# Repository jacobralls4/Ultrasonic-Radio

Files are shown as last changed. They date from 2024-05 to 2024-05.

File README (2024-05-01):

This repo contains many files related to Team 84s Ultrasonic Radio Project. Here you can find key design files shown through Spice, Altium, and ss from multisim.
Along with this there are report files as well as a few of our presentation slides.
Additionally you can find screenshots showcasing key oscilloscope waveforms demonstrating successful validations of our project.

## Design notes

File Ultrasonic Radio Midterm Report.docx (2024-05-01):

Ultrasonic Radio

Nathan Cinocca

Concept of Operations

REVISION – Draft

25 January 2018

Concept of Operations

for

Ultrasonic Radio

Team 84

Approved by:

_____________________________

Project Leader Date

_____________________________

Prof. Kalafatis Date

_____________________________

T/A Date

Change Record

Rev. | Date | Originator | Approvals | Description
- | 9/14/2023 | Nathan Cinocca | | Draft Release

4.2. Submarine Communications………………………………………………………………4

# No table of figures entries found.

# 1. Executive Summary

Communicating information is an important aspect of almost any military operation. However, depending on the situation, it can be difficult to transmit information safely. For example, in planes and submarines it is difficult to communicate with regular equipment as the electromagnetic waves will interfere with the vehicles navigating equipment. To solve this issue, an ultrasonic radio will be developed that will operate at a low frequency using acoustic waves outside of the range of human hearing. The radio will also have multiple channels that will allow for two-way communications between correspondents. Ultimately, this radio will allow for better communication between military operators even around areas that are sensitive to electromagnetic waves.

# 2. Introduction

This report is an introduction to the development of an ultrasonic radio. This ultrasonic radio will be designed to operate using low frequency acoustic waves outside of the range of human hearing to transmit data without affecting other electromagnetic waves at higher frequencies. This ultrasonic radio will primarily be used for military operations that involve planes, submarines, and other forms of transportation with sensitive equipment. However, this radio could also be used by civilians in similar situations.

## 1.1. Background

Radios have been around for a very long time and operate at a large range of frequencies from 3 Hz to 300 GHz. However, most of these radios use electromagnetic waves to transmit information. Radios that use electromagnetic waves are effective methods of communication as they can send and receive information very quickly. Despite this electromagnetic wave-based communication can have problems where multiple devices create wave interference. This can be a very dangerous issue when sensitive, vital equipment such as airplane equipment is interfered with. The danger of electromagnetic wave interference is multiplied in dangerous military situations.

A way to get around the limitations posed by electromagnetic waves and their applications is to create an ultrasonic radio that uses acoustic waves. Using acoustic waves at lower frequencies will allow for minimal electromagnetic interference but will limit range of transmission. This trade off is acceptable as it will allow for safe communication during military operations in both planes and submarines.

In my research I have only found one ultrasonic acoustic radio that has been developed. This radio was developed by Qin Zhou, Jinglin Zhenga, Seita Onishia, M. F. Crommie, and Alex K. Zettl. Their ultrasonic radio is designed to operate at a band centered around 300 kHz with only a single channel. Their design is effective, but I plan to improve upon it by lowering the operational frequency to have less interference. I also plan to add multiple channels to allow for two-way communication.

## 1.2. Overview

There are many different parts involved in creating this ultrasonic radio and a large focus for this project will be designing individual parts. An overview of the components involved in this radio is as follows. Firstly, the incoming signal will be amplified using a transistor-based amplifier. Then the signal will be filtered using a bandpass circuit and moved to a higher frequency, if necessary, with a mixer. Next, the signal will be modulated using frequency modulation. Then the signal will be filtered once more for noise and amplified with a power amplifier of very large gain (~100 dB). After this the signal will pass through the input transducer and the output transducer. After the signal passes through the output transducer the signal will be amplified again using a transistor-based amplifier, and then filtered. Finally, the signal may be filtered again to reduce noise before the final signal is output.

## 1.3. Referenced Documents and Standards

- Graphene electrostatic microphone and ultrasonic radio (pnas.org) (https://www.pnas.org/doi/pdf/10.1073/pnas.1505800112)
- C95.1, Standard for Safety Levels with Respect to Human Exposure to Radio-Frequency Electromagnetic Fields, 3 kHz to 300 GHz

# 3. Operating Concept

## 1.4. Scope

The ultrasonic radio is primarily intended to be used for military operations in areas where electromagnetic communications are difficult. This primarily includes during plane and submarine transportation. The ultrasonic radio could also be used at a lower capacity by regular consumers during flights.

## 1.5. Operational Description and Constraints

The ultrasonic radio should be simple to operate and will be operable without any in-depth knowledge or training. Essentially you should be able to speak on one side of the radio and hear the output of your voice on the other side in relative clarity. The radio will also allow you to both speak and listen to noise at the same time. This will be accomplished through two frequency channels.

There are several constraints that come with this project. One of them is the cost constraint. As a capstone student, I am afforded $100 to spend on our project. Since I will need to purchase transducers at an absolute minimum which can be relatively expensive. Because of this I will most likely be using discrete components to design the amplifiers and filters. This will lead to more noise and less precision in the designs. Another constraint on this ultrasonic radio is that since the system will be using acoustic waves, the transmission of information will be slower than most electromagnetic wave transmissions.

## 1.6. System Description

The ultrasonic radio can be divided into roughly five different parts. These include signal amplifiers, filters, signal modulator/demodulator, power amplifier, and the input/output transducers.

The signal amplifier will be used to amplify the noise input and output from the radio. The signal amplifier will be designed from discrete transistors. I will attempt to keep the power consumption relatively low by limiting the voltage <10 V and current to <15mA.

The filters will primarily be used to get rid of noise. I will use an IC operational amplifier for this application instead of designing the amplifier from scratch. For the filters used for both the input and output signal I will need them to operate at two different frequencies to accommodate the different channel frequencies. These frequencies will be in the 50k Hz to 100k Hz range.

Next, I will need to design a frequency modulator and demodulator. To do this I will need an oscillator and some IC op amps. This will also include many resistors and capacitors to operate properly.

I will also design a power amplifier with transistors. This amplifier will need to have a very large gain of around 100 dBs. This will be important to allow the signal to be transmitted a large distance.

Finally, I will need to purchase transducers that will function with the rest of the circuit. They will also need to function within the channel frequencies of 50k Hz – 100kHz.

## 1.7. Modes of Operations

Many radios are only half-duplex and only allow for one party to speak at a time. With this set up, a button is typically needed to activate the transmission from one radio to the other. However, since this ultrasonic radio will be full-duplex and allow for both parties to speak at the same time, there will be no need for this mode.

Instead, ultrasonic will simply have two modes. The first being the on mode, or the mode that will allow signal transmission. The other mode will be the off mode where no power will be consumed, and no signal will transmit.

## 1.8. Users

The ultrasonic radio is primarily intended to be used by military personnel usually during plane and submarine transportation. The ultrasonic radio could also be used at a lower capacity by regular consumers during flights. The radio should be able to be used with very little experience and a short manual. Overall, the radio should be usable by both the military and civilians with relative ease.

## 1.9. Support

The ultrasonic radio will be intuitive to use and as such should be usable without many instructions. However, a short manual would be provided with some instructions should it be needed.

# 4. Scenario(s)

## 1.10. Plane Communications

The first scenario in which the ultrasonic radio could be used is in the case of plane transportations. To avoid the impact of electromagnetic waves the ultrasonic radio could be used by both military personnel and civilians traveling in planes. This would allow communication between individuals on and off the plane.

## 1.11. Submarine Communications

Similar to the first scenario the ultrasonic radio could be used to avoid electromagnetic wave interference with submarine instruments. This scenario is less applicable to the public as few civilians use submarines for transportation. The radio would allow contact between submarines or contact between submarines and individuals on land depending on the distance.

# 5. Analysis

## 1.12. Summary of Proposed Improvements

- Allows for safer communication around equipment sensitive to electromagnetic waves
- Improves upon old design to allow both parties to speak and listen simultaneously
- Communication system is easy to use

## 1.13. Disadvantages and Limitations

- The ultrasonic radio with acoustic waves will have less range than an electromagnetic radio
- Increased noise due to cheaper components from budget limitations
- Slower transfer of information due the low operational frequency

## 1.14. Alternatives

- Improved electromagnetic shielding
  - Shield sensitive plane/submarine components from all other EM waves so that regular electromagnetic communications can be used
  - Could be more effective but would be much more expensive and technically difficult

## 1.15. Impact

- The ultrasonic radio must abide by radio frequency standards
- The radio may be used to gain a tactical advantage in military operations

Ultrasonic Radio

Nathan Cinocca

Functional System Requirements

REVISION – Draft

28 September 2023

Functional System Requirements

for

Ultrasonic Radio

Prepared by:

Team 84

Approved by:

_____________________________

Nathan Cinocca Date

_____________________________

John Lusher, P.E. Date

_____________________________

T/A Date

Change Record

Rev. | Date | Originator | Approvals | Description
- | 9/28/2023 | Nathan Cinocca | | Draft Release

Table 2. Reference Documents……………………………………………….3

# 6. Introduction

## 1.16. Purpose and Scope

This document covers the functional system requirements for the project. The purpose of the project is to provide an alternative way to send communications that does not use electromagnetic waves. By limiting the creation of electromagnetic radiation, this ultrasonic radio will allow for communications in locations that are susceptible to electromagnetic interference. To do this, the radio will operate at lower ultrasonic frequencies as opposed to higher electromagnetic wave frequencies. Additionally, acoustic waves will be used instead of electromagnetic waves.

This specification defines the technical requirements for the development items and support subsystems delivered to the client for the project. Figure 1 shows a representative integration of the project in the proposed CONOPS. The verification requirements for the project are contained in a separate Verification and Validation Plan.

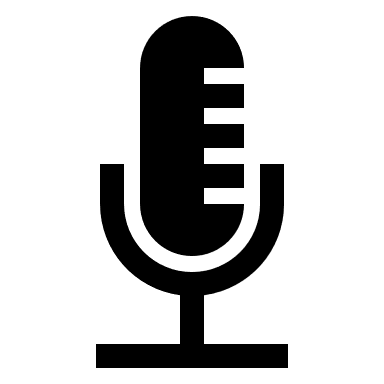
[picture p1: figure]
Radio microphone with solid fill
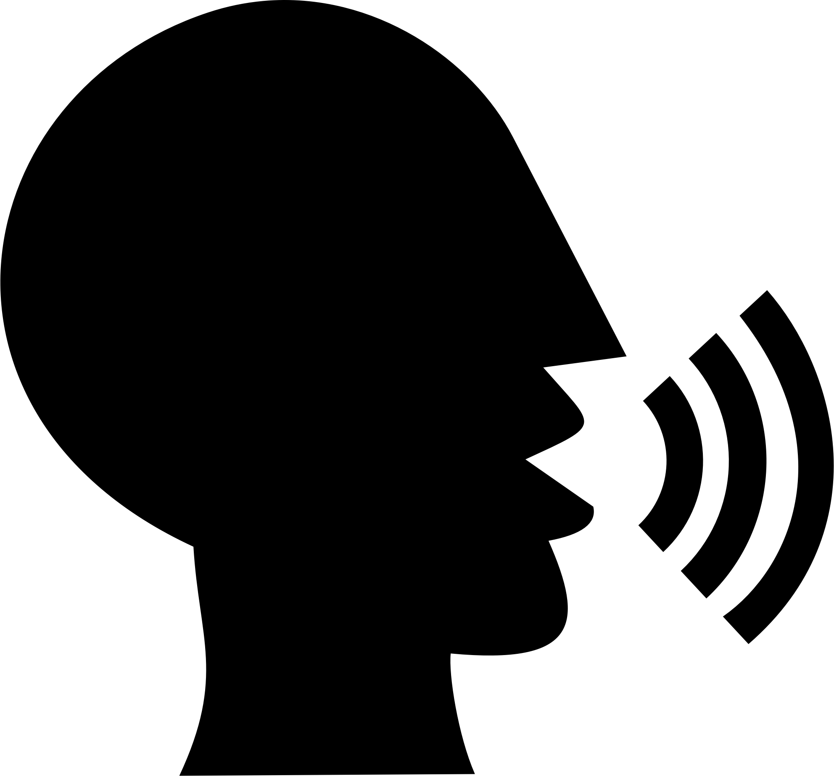
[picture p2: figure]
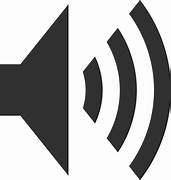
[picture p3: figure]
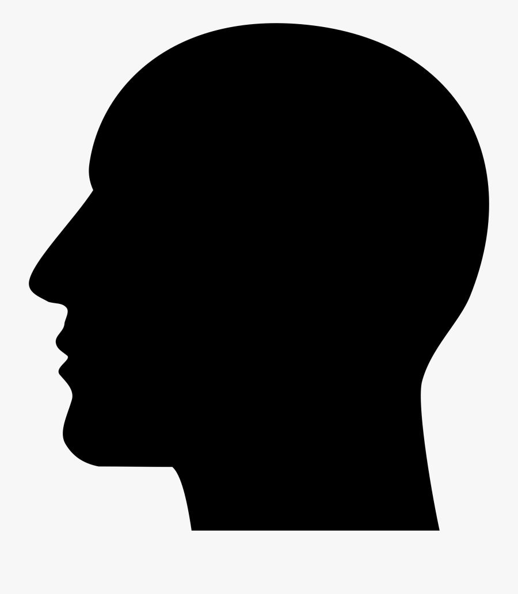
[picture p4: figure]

Microphone

Microphone

Speaker

Speaker

Ultrasonic Waves

Figure 1. Ultrasonic Radio Conceptual Image

The following definitions differentiate between requirements and other statements.

Shall: This is the only verb used for the binding requirements.

Should/May: These verbs are used for stating non-mandatory goals.

Will: This verb is used for stating facts or declaration of purpose.

## 1.17. Responsibility and Change Authority

The sole team member, Nathan Cinocca, will be responsible for verifying the requirements of the project are achieved. Any changes to the project may only be enacted through an agreement between Nathan Cinocca and the sponsor Dr. Oscar Moreira. Subsystem ownership for this project is listed below.

- Nathan Cinocca: Signal Amplifier, Filters, Modulator/Demodulator, and Power Amplifier

# 7. Applicable and Reference Documents

## 1.18. Applicable Documents

The following documents, of the exact issue and revision shown, form a part of this specification to the extent specified herein:

Document Number | Revision/Release Date | Document Title
IPC A-610E | Revision E – 4/1/2010 | Acceptability of Electronic Assemblies
MIL-STD-461 | Revision E – 8/20/1999 | Requirements for the Control of Electromagnetic Interface Characteristics of Subsystems and Equipment
ΙΕΕΕ Standard C95.1 | 4/16/1999 | Safety Levels with Respect to Human Exposure to Radio Frequency Electromagnetic Fields, 3 kHz to 300 GHz

Table 1. Applicable Documents

## 1.19. Reference Documents

The following documents are reference documents utilized in the development of this specification. These documents do not form a part of this specification and are not controlled by their reference herein.

Document Number | Revision/Release Date | Document Title
1 | 2015 | Graphene electrostatic microphone and ultrasonic radio
2 | 2010 | Analog and Digital Communications
3 | 2011 | RF and Microwave Transmitter design
4 | 2014 | FM Modulation/de-modulation circuit
5 | 2009 | Engineering Acoustics: An Introduction to Noise Control
5 | 2020 | Thermal Stress Inside a Disabled Submarine

Table 2. Reference Documents

## 1.20. Order of Precedence

In the event of a conflict between the text of this specification and an applicable document cited herein, the text of this specification takes precedence without any exceptions.

All specifications, standards, exhibits, drawings or other documents that are invoked as “applicable” in this specification are incorporated as cited. All documents that are referred to within an applicable report are considered to be for guidance and information only, except ICDs that have their relevant documents considered to be incorporated as cited.

# 8. Requirements

This section defines the minimum requirements that the development item(s) must meet. The requirements and constraints that apply to performance, design, interoperability, reliability, etc., of the system, are covered.

## 1.21. System Definition

Provide a brief overview of the project, and then describe some of the main sub-systems of your proposed solution.

The ultrasonic radio is a method of communication that limits the creation of electromagnetic waves so electromagnetic interference is minimized. By minimizing the emission of electromagnetic waves, this communication device will allow for information transfer around devices sensitive to other electromagnetic waves. This ultrasonic radio will limit electromagnetic wave emission by using acoustic waves and low ultrasonic frequencies to transmit information. The ultrasonic radio is largely made up of five different subsystems. These subsystems include: the signal amplifier, filters, power amplifier, modulator/ demodulator, and the speakers/microphones.

Voice Input

Demodulator

Amplifier and Filter

Transmitter/ Receiver

Filter and Power Amplifier

Modulator

Amplifier and Filter

Filter and Output Voice

Figure 2. Block Diagram of System

The first part of the ultrasonic radio is the input microphone which will operate to encompass human voice frequencies. This range of operational frequencies will be around 100 Hz to 3 kHz. This microphone will translate the voice into an electrical signal that will then be amplified and filtered through the signal amplifier and low frequency filter. This will make the signal stronger and filter out unneeded noise being picked up by the microphone. Following this, the signal will go through a modulating circuit which moves the input signal to ultrasonic frequencies to prepare for transmission. After modulation, the signal may be filtered if additional noise is picked up at the higher ultrasonic frequency. Then the modulated signal will go through the power amplifier which will give the signal the desired gain to transmit through the ultrasonic speaker to the ultrasonic microphone some distance away. Once the signal is picked up by the microphone it will be filtered and amplified again to prepare for demodulation. Then the signal will be demodulated down to frequencies within the range of human hearing. Finally, the signal may be filtered again if necessary and then it will be output through a speaker operating within the range of human hearing.

## 1.22. Characteristics

### 8.1.1. Functional / Performance Requirements

#### 8.1.1.1. Signal to Noise Ratio

The transferred signal from the ultrasonic radio shall have at least a 60 dB signal to noise ratio.

Rationale: Typical audio equipment that functions well has a signal to noise ratio of at least 60 dB. Very good audio equipment has even higher decibels. Since the ultrasonic radio should have a clear signal so communications can happen cleanly 60 dB is required.

#### 8.1.1.2. Transmission Distance

The ultrasonic radio shall meet a communication distance of 15 meters or more.

Rationale: Although a long transmission distance for the ultrasonic radio is better, there are limitations from testing and the ultrasonic nature of the waves. Knowing this, a transmission distance of 15 meters or more will allow for a usable and testable ultrasonic radio.

#### 8.1.1.3. Total Harmonic Distortion

The ultrasonic radio shall have a total harmonic distortion of less than or equal to 5%.

Rationale: It is important to keep total harmonic distortion low to keep good audio quality. Typically, a total harmonic distortion level less than or equal to 5% is acceptable and is the goal for this ultrasonic radio.

### 8.1.2. Physical Characteristics

#### 8.1.2.1. Mass

The mass of the ultrasonic radio shall be less than or equal to 10 kilograms.

Rationale: While there isn’t a specific weight requirement for the ultrasonic radio, it should be relatively easy to move around for maximum use. A weight of up to 10 kilograms should be easy for any military man/woman to move.

### 8.1.3. Electrical Characteristics

#### 8.1.3.1. Inputs

The electrical inputs should not be changed by users of the ultrasonic radio. All tests will be performed under these conditions and system performance under separate conditions is not guaranteed.

##### 8.1.3.1.1 Power Consumption

The maximum peak power of the system shall not exceed 4.5 watts.

Rationale: This requirement is due to the power of the system being provided by a USB wall adapter. The maximum power provided by USB 3.0 is 4.5 watts, so that is the maximum power limit.

##### 8.1.3.1.2 Input Voltage Level

The input voltage level for the ultrasonic radio shall be +5 VDC.

Rationale: USB wall adapter has a voltage level of 5 VDC which will be used to power the ultrasonic radio.

##### 8.1.3.1.3 Input Current Level

The input current for the ultrasonic radio shall not exceed 900 mA.

Rationale: 900 mA is the maximum current that can be supplied by the USB 3.0 wall adapter and is thus the maximum current that can be supplied to the ultrasonic radio.

##### 8.1.3.1.4 Voice Input

The ultrasonic radio shall take user voice input that operates from 100 Hz to 3 kHz.

Rationale: The ultrasonic radio needs to be able to handle any range of human voice frequencies and transmit them.

#### 8.1.3.2. Outputs

##### 8.1.3.2.1 Voice Output

The ultrasonic radio shall output the voice input up to 15 meters away at frequencies 100 Hz to 3 kHz.

Rationale: The ultrasonic radio will allow communications to pass into the microphone and out through the output speaker a distance up to 15 meters away to satisfy the conditions of a radio.

### 8.1.4. Environmental Requirements

The ultrasonic radio shall be designed to withstand and operate in the environments and laboratory tests specified in the following section.

Rationale: This is a requirement specified by the intended usage of the ultrasonic radio

#### 8.1.4.1. Pressure (Altitude)

The ultrasonic radio may be able to operate up to 2.5 atm of pressure.

Rationale: The internal pressure of a typical military submarine is roughly equivalent to 2.5 atm. Thus, to perform its function, the ultrasonic radio should be able to function up to this amount of pressure.

#### 8.1.4.2. Thermal

The ultrasonic radio may be able to operate at thermal temperatures ranging from 55 degrees Fahrenheit to 95 degrees Fahrenheit.

Rationale: The internal thermal temperatures of a military submarine without power can range from 55 degrees Fahrenheit to 95 degrees Fahrenheit in extreme scenarios. So, the ultrasonic radio should be able to function in these emergencies.

#### 8.1.4.3. Humidity

The ultrasonic radio should be able to function in 0-95% relative humidity.

Rationale: The internal relative humidity of a military submarine without power can range from 0-95% relative humidity in extreme scenarios. So, the ultrasonic radio should be able to function in these emergencies.

### 8.1.5. Failure Propagation

##### 3.2.5.1 Recovery

The Ultrasonic radio should provide a way to reset the entire system.

Rationale: This is a feature of the radio that should help fix errors that occur with the ultrasonic radio.

# 9. Support Requirements

4.1.1 Ultrasonic Radio Manual

To help users understand how to use the ultrasonic radio, a manual that details some of the parts of the radio and generally how to use it will be provided to customers.

Rationale: This feature will help users better understand the ultrasonic radio which will allow for improved usage of the device.

4.1.2 Power Adapter

Users of the ultrasonic radio will be provided with a USB power adapter to power the radio. However, clients must have access to a wall outlet to use the USB adapter and power the radio.

Rationale: Providing the power adapter will ensure that the correct power source is used for the ultrasonic radio. It will also allow the users to spend less time before the radio is operational.

# Appendix A: Acronyms and Abbreviations

ATM Atmosphere

CONOPS Concept of Operations Document

dB Decibels

Hz Hertz

ICD Interface Control Document

Kg kilograms

kHz Kilohertz (1,000 Hz)

mA Milliamp

MHz Megahertz (1,000,000 Hz)

SNR Signal to Noise Ratio

USB Universal Serial Bus

VDC Direct Current Voltage

# Appendix B: Definition of Terms

Electromagnetic waves Waves produced by the movement of electric charge and the propagation of electric and magnetic fields.

Electromagnetic radiation When electromagnetic waves interfere with each other when they should not

Receiver Equipment that accepts transmitted waves carrying signals from another location

Transmitter Equipment that generates and transmits waves carrying signals to another location

Ultrasonic A range of frequencies from 20 kHz to 20 MHz

Ultrasonic Radio

Nathan Cinocca

Interface Control Document

REVISION – Draft

28 September 2023

Interface Control Document

for

Ultrasonic Radio

Prepared by:

Team 84

Approved by:

_____________________________

Nathan Cinocca Date

_____________________________

John Lusher II, P.E. Date

_____________________________

T/A Date

Change Record

Rev. | Date | Originator | Approvals | Description
- | 9/28/2023 | Nathan Cinocca | | Draft Release

# No table of figures entries found.

# 10. Overview

This Interface Control Document (ICD) will provide detail on how the various subsystems of the ultrasonic radio will function together. This document will also detail physical descriptions of various subsystems of the ultrasonic radio. The Interface Control Document will also explain how the subsystems will interface together to meet the requirements explained in the Functional System Requirements document and ConOps document.

# 11. References and Definitions

## 1.23. References

Refer to section 2.2 in the Functional System Requirements document.

## 1.24. Definitions

ATM Atmosphere

CONOPS Concept of Operations Document

dB Decibels

Hz Hertz

ICD Interface Control Document

Kg kilograms

kHz Kilohertz (1,000 Hz)

mA Milliamp

MHz Megahertz (1,000,000 Hz)

Mm Millimeter

mW Milliwatt

SNR Signal to Noise Ratio

TBD To be determined

USB Universal Serial Bus

VDC Direct Current Voltage

W Watt

# 12. Physical Interface

## 1.25. Weight

The overall weight of the system is difficult to determine at the current time as many of the subsystems have not been designed yet. The design of the systems will determine how many transistors, resistors, capacitors, and operational amplifiers will be used. All these components are light and should not add excessive weight. The heaviest subsystem in the ultrasonic radio will be the speakers and microphones. Although the speakers and microphones will be heavier compared to the transistors and other circuit elements, they are still quite small and light. Thus, it should not be difficult to keep the entire radio under 10 kilograms.

## 1.26. Dimensions

The dimensions of the entire ultrasonic radio should be kept under 1 cubic foot in size.

Similar to the weight section, since many subsystems are still being designed it is difficult to give accurate dimensions for each of the subsystems. However, most of the components are quite small. For example, the 2N3904 transistor which will be used is 36 mm x 18 mm x 1.5 mm. So, even using 100 transistors will still allow lots of space for the microphones, operational amplifiers, and other circuit elements. Op amp 743, which will be used in filters, and modulation/demodulation circuits has dimensions of 356 mm x 356 mm x 35 mm, which again is small even if many are used. Currently, the microphones and speakers that are being considered are also small at about 10 mm x 10mm x 3.5 mm. Since all the parts are small the ultrasonic radio should be able to meet the dimension requirement of 1 cubic foot.

# 13. Thermal Interface

Since the ultrasonic radio will be functioning at relatively low power, it will not need any heat sink to maintain low heat and high efficiency.

# 14. Electrical Interface

## 1.27. Primary Input Power

The ultrasonic radio has a maximum power of 4.5 watts. More specifically this is 5 V and 900 mA of current supplied by a USB 3.0 adapter. Although the power supplied to each subsystem is TBD at this point, since most are being designed, some maximum power requirements can be determined. This will be discussed in section 5.2.

## 1.28. Voltage and Current levels

- Signal amplifiers shall have no more than 50 mA and 5 V for 250 mW of power
- Filters shall have no more than 15 mA and 5 V for 75 mW of power
- Modulator/demodulators shall have no more than 100 mA and 5 V for 500 mW of power
- Power amplifiers shall have no more than 300 mA and 5 V for 1.5 W of power
- Speaker and microphones shall have no more than 350 mA and 5 V for 1.75 W of power

# 15. Communications / Device Interface Protocols

## 1.29. Communications Safety

Although this radio operates at a frequency that can not be heard by the human ear. The ultrasonic radio can still cause hearing loss from excessive exposure to ultrasonic frequencies. Thus, clients that are using the ultrasonic radio for extended amounts of time should wear ear protection.

Ultrasonic Radio

Nathan Cinocca

Schedule and Validation

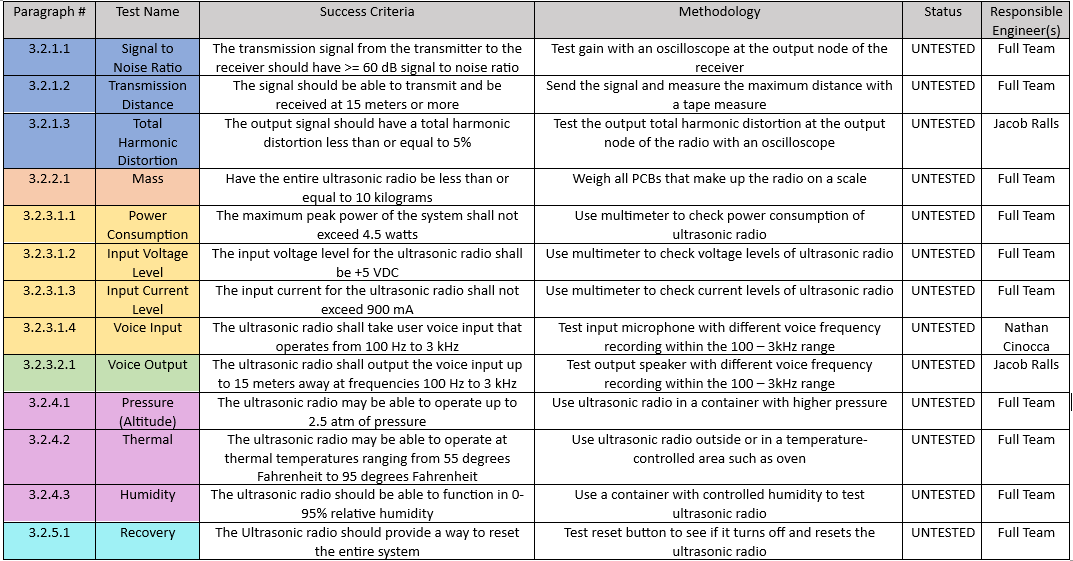
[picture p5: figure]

Calibrated LWIR Raw Video Data Collection - Gold Standard – Test 1 Revision -

Concept of Operations Revision – Draft Project Name

Functional System Requirements Revision - Draft Ultrasonic Radio

Schedule and Validation Revision - Ultrasonic Radio

Concept of Operations Revision - Project Name

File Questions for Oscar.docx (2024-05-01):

Questions for Oscar

- How high of a gain would be required to transmit the signal maybe 50 feet? Or how would I figure that out?
  - Want 60 dB signal to noise ratio
  - Some is lost in transmission
- How much gain for the signal amplifier?
- What 5V supply did you mention in our meeting before?
  - 5v usb adapter 1 W
- 3.2.4. Environmental Requirements The Search and Rescue System shall be designed to withstand and operate in the environments and laboratory tests specified in the following section. Rationale: This is a requirement specified by our customer due to constraints of their system in which the Search and Rescue System is integrating. 3.2.4.1. Pressure (Altitude) 3.2.4.2. Thermal 3.2.4.3. External Contamination 3.2.4.4. Rain 3.2.4.5. Humidity etc....you get the idea

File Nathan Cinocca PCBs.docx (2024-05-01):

Nathan Cinocca PCBs

Signal ampllifier

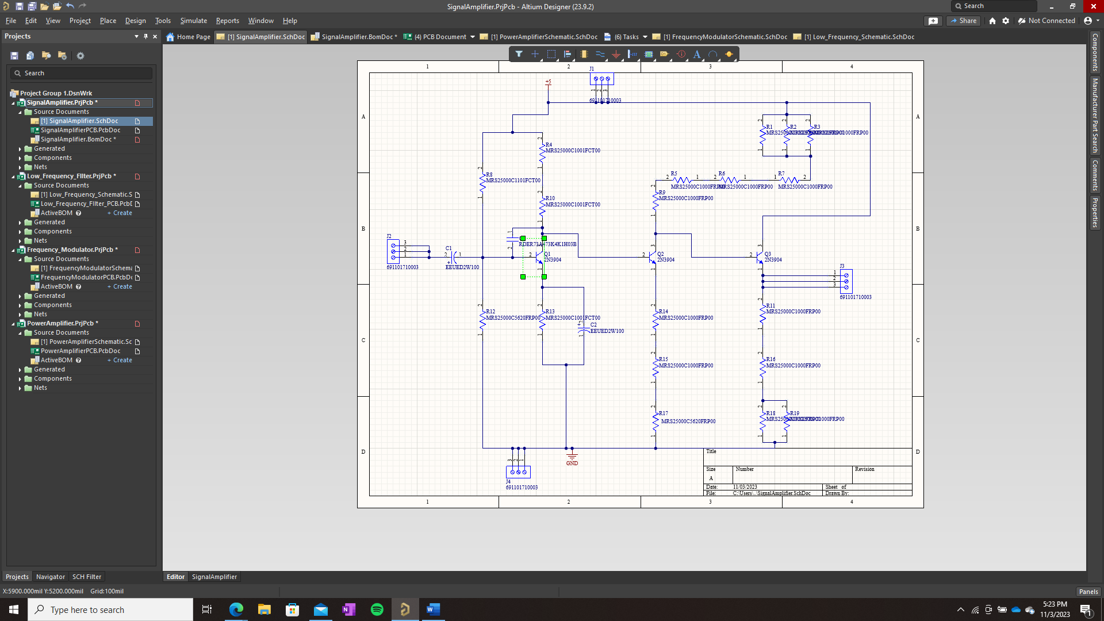
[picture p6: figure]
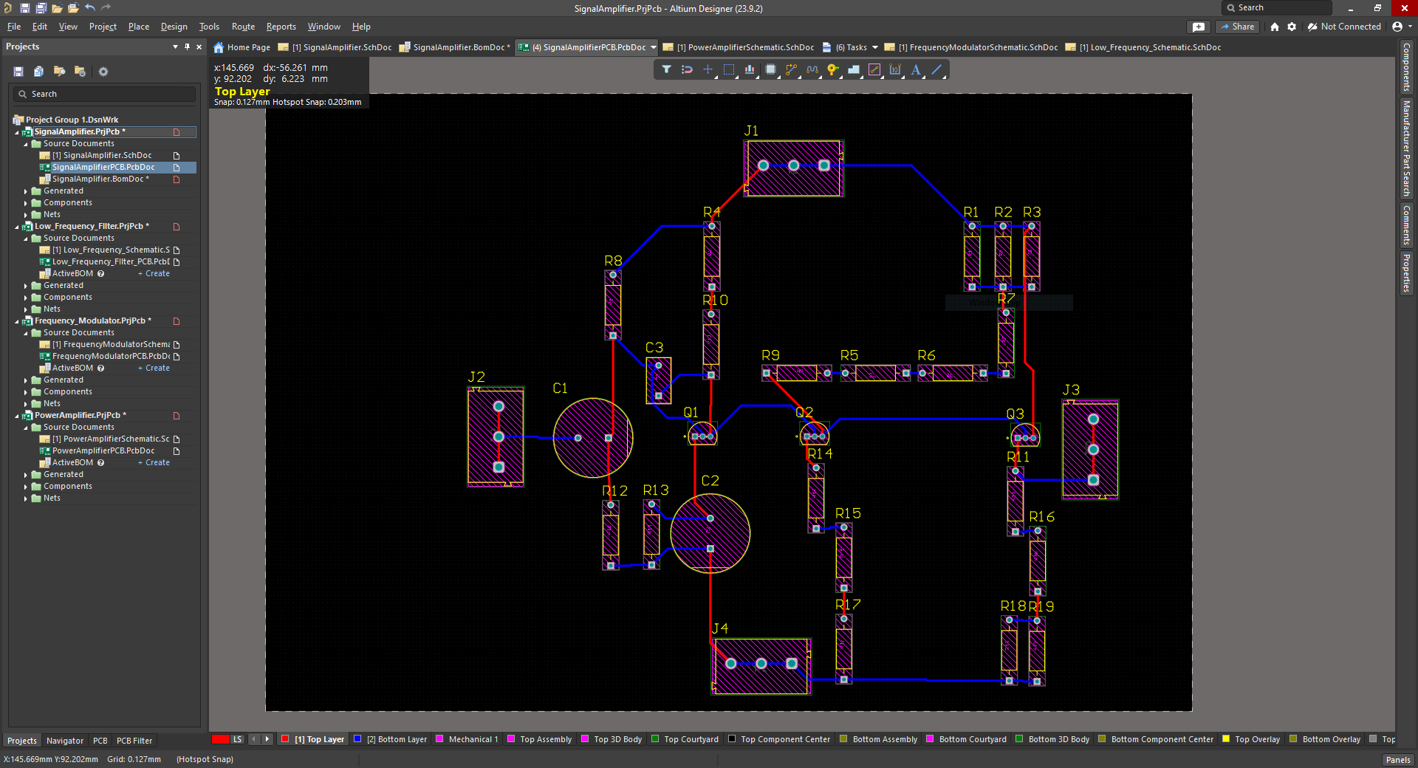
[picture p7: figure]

Filter

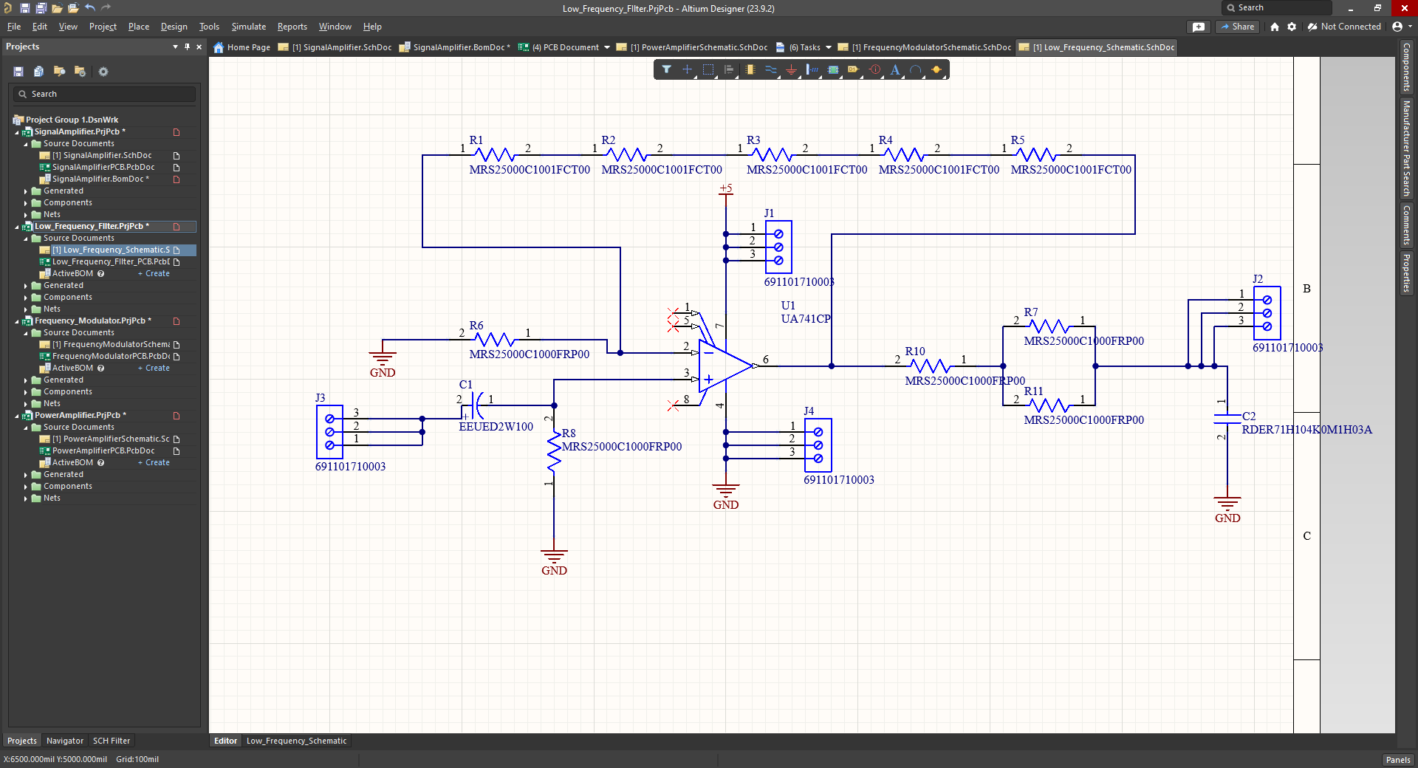
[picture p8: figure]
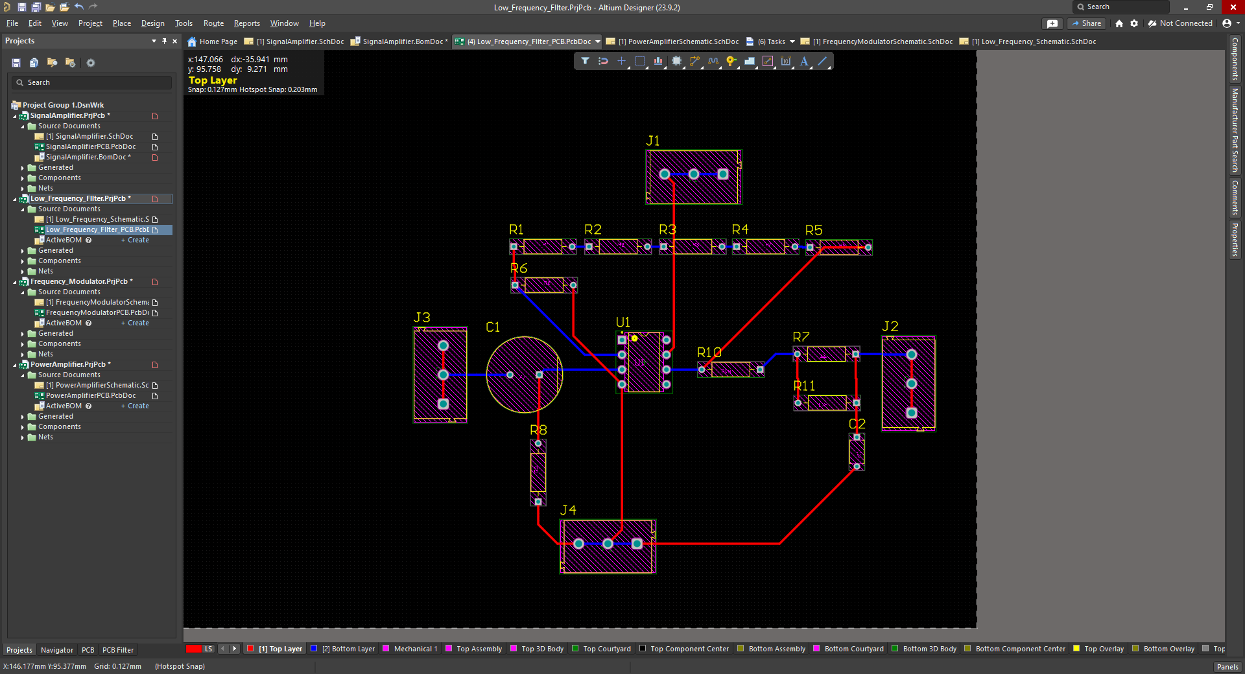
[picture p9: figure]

Frequency Modulator

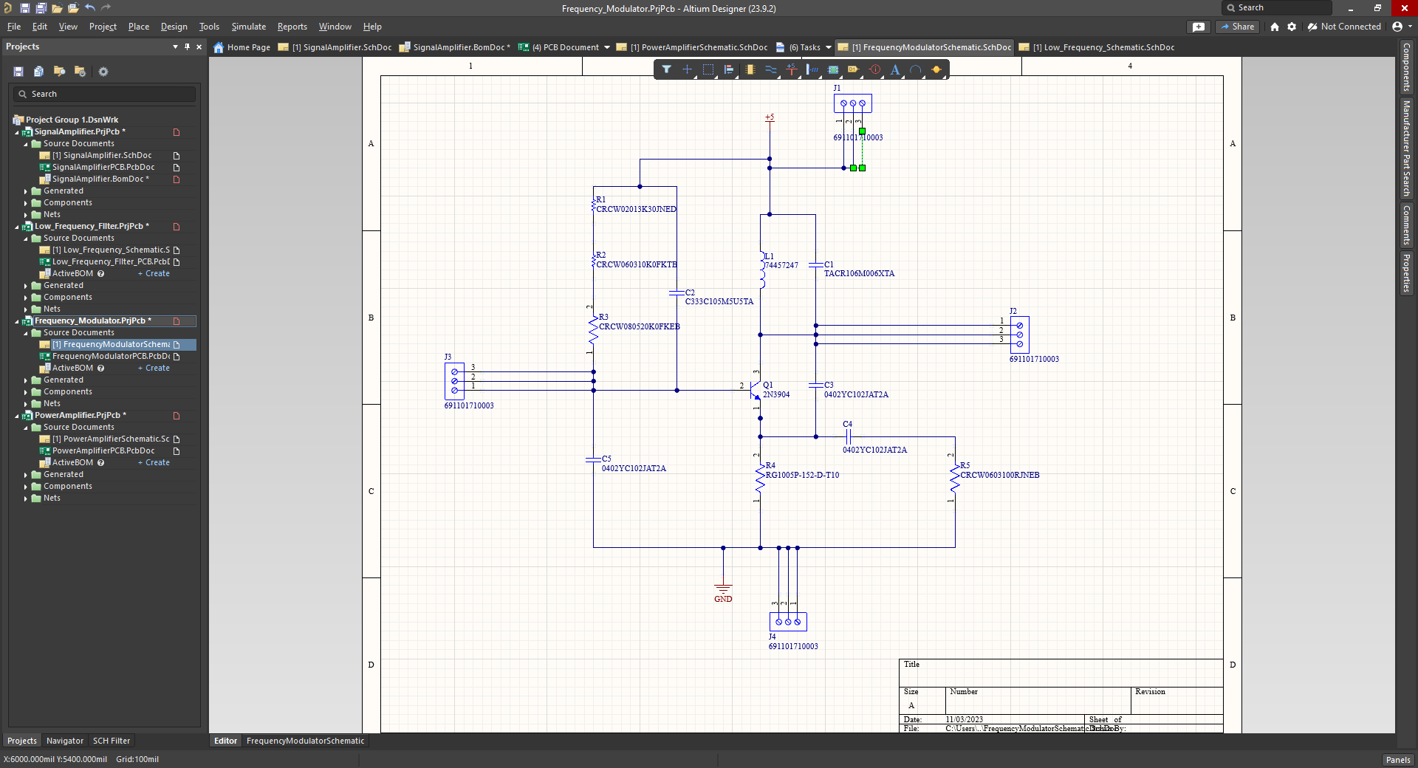
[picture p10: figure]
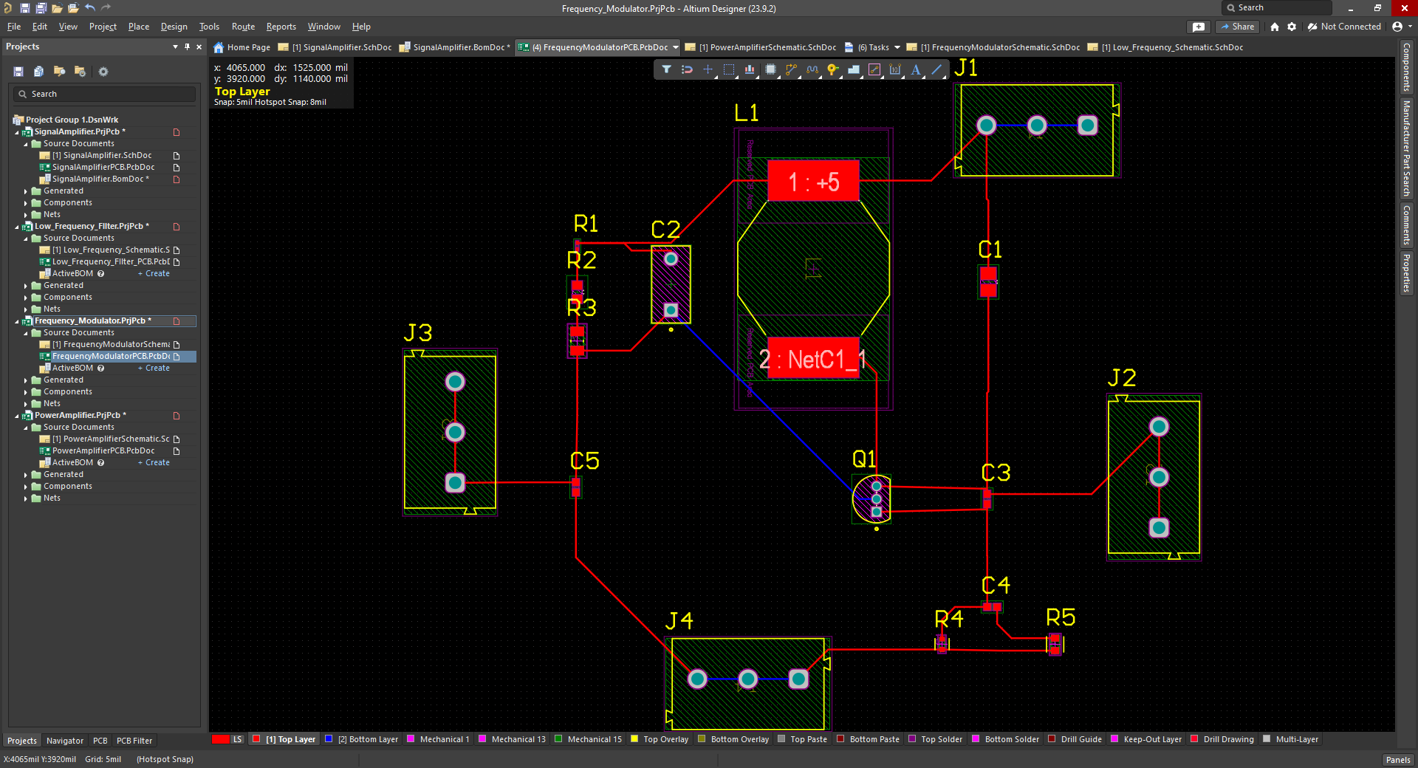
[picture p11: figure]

Power Amplifier

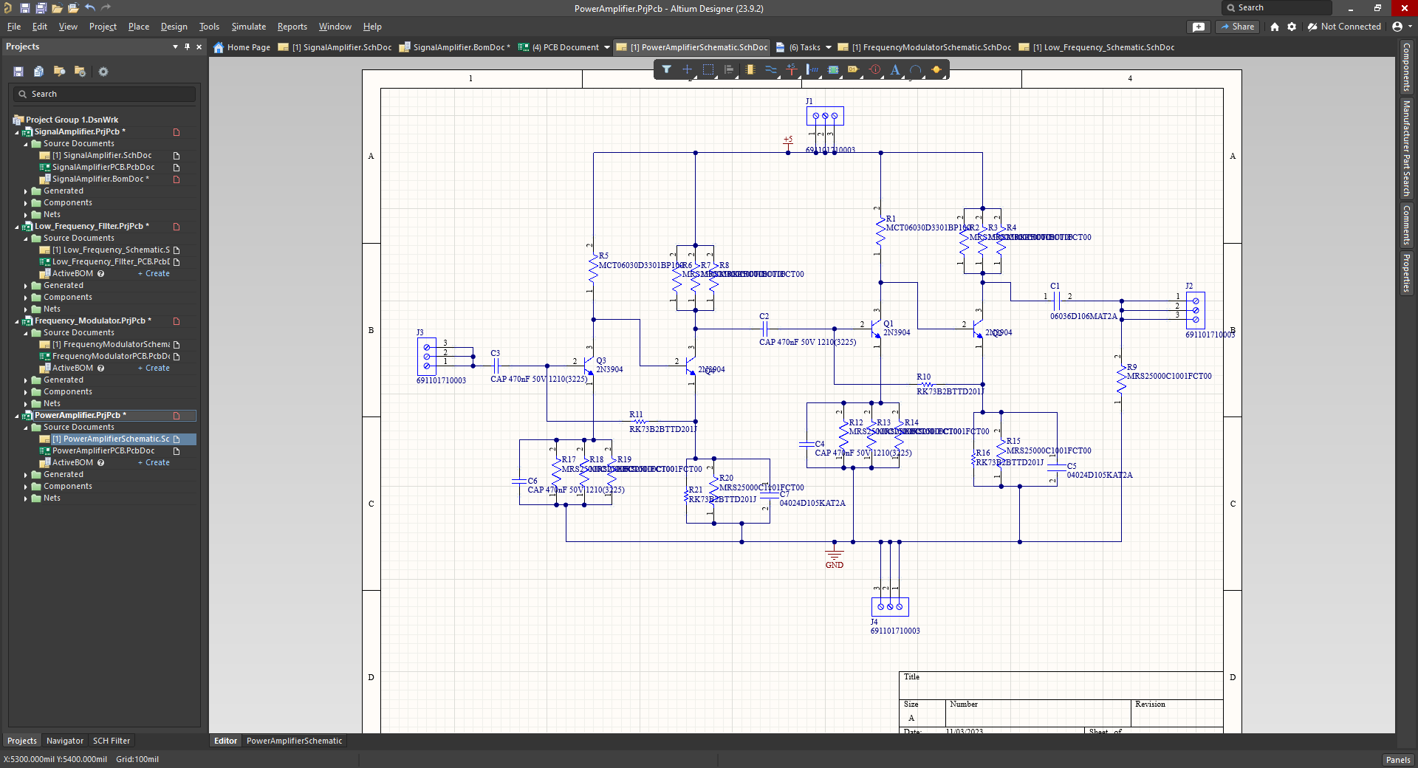
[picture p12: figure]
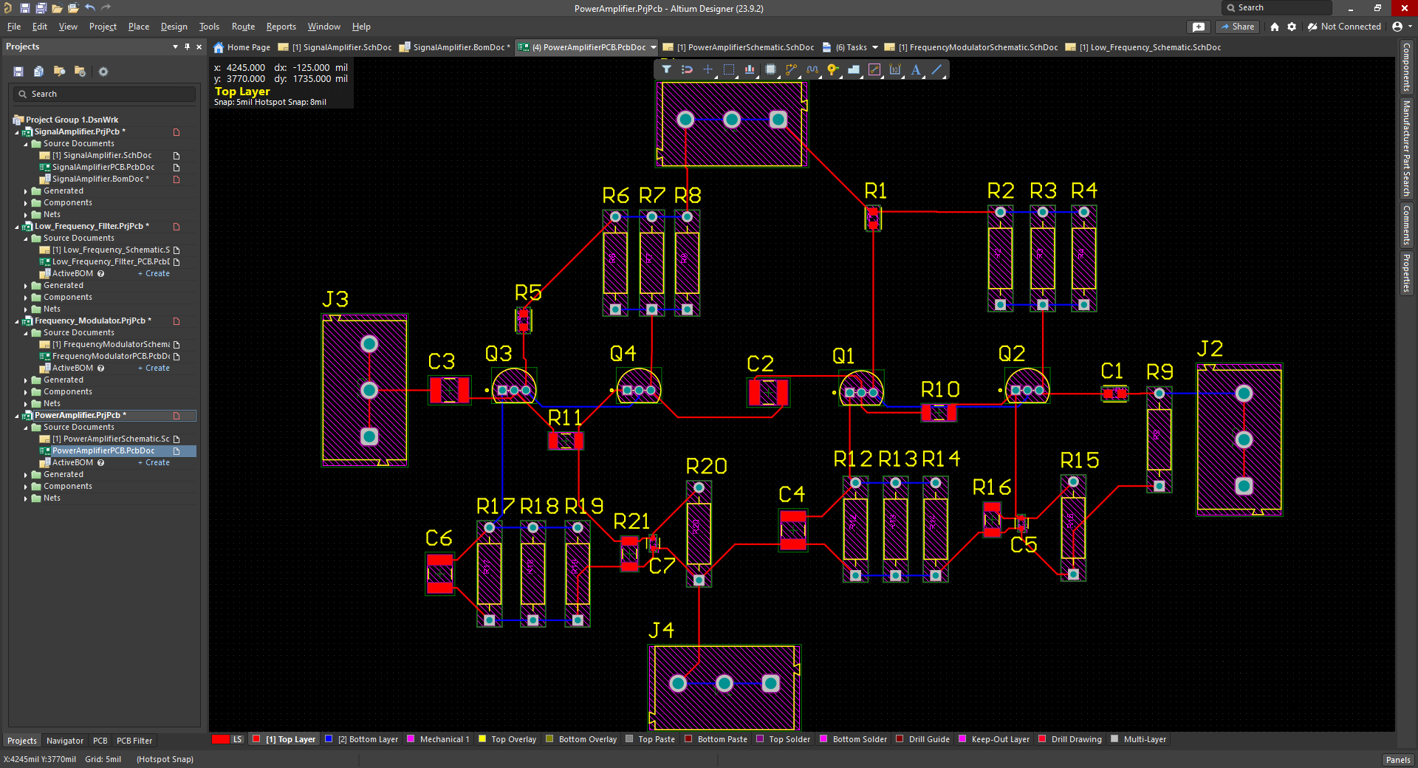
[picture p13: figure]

Paragraph # | Test Name | Success Criteria | Methodology | Status | Responsible Engineer(s)
13.2.1.1 | Total Harmonic Distortion | The output signal should have a total harmonic distortion less than or equal to 10% | Test the output total harmonic distortion at the output node of the radio with an oscilloscope | TESTED | Jacob Ralls
13.2.1.2 | Frequency Match | The transmitted signal frequency and tuned demodulator frequency should be matched within 3 kHz | Measure the modulator frequency and demodulator frequency with an oscilloscope | TESTED | Full Team
13.2.2.1 | Mass | Have the entire ultrasonic radio be less than or equal to 10 kilograms | Weigh all PCBs that make up the radio on a scale | TESTED | Full Team
13.2.3.1.1 | Power Consumption | The maximum peak power of the system shall not exceed 4.5 watts | Use multimeter to check power consumption of ultrasonic radio | TESTED | Full Team
13.2.3.1.2 | Input Voltage Level | The input voltage level for the ultrasonic radio shall be +5 VDC for the transmitter and +9 VDC for receiver | Use multimeter to check voltage levels of ultrasonic radio | TESTED | Full Team
13.2.3.1.3 | Input Current Level | The input current for the ultrasonic radio shall not exceed 900 mA | Use multimeter to check current levels of ultrasonic radio | TESTED | Full Team
13.2.3.1.4 | Voice Input | The ultrasonic radio shall take user voice input that operates from 100 Hz to 3 kHz | Test input microphone with different voice frequency recording within the 100 – 3kHz range | TESTED | Nathan Cinocca
13.2.3.2.1 | Voice Output Frequency | The ultrasonic radio shall output the voice input at frequencies 100 Hz to 3 kHz | Test output speaker with different voice frequency recording within the 100 – 3kHz range | TESTED | Jacob Ralls
13.2.3.2.2 | Voice Output Volume | The ultrasonic radio shall be heard from up to 15 meters away | Measure output volume in decibels to determine audible distance of output noise | TESTED | Jacob Ralls
13.2.4.1 | Pressure | The ultrasonic radio may be able to operate at 1 atm of pressure | Use ultrasonic radio in a standard room with 1 atm of pressure | TESTED | Full Team
13.2.4.2 | Thermal | The ultrasonic radio may be able to operate at thermal temperatures ranging from 55 degrees Fahrenheit to 95 degrees Fahrenheit | Use ultrasonic radio outside at different temperatures | TESTED | Full Team
13.2.5.1 | Recovery | The Ultrasonic radio should provide a way to reset the entire system | Reset the system by unplugging power supply from both transmitter and receiver for 10 seconds to reset system | TESTED | Full Team

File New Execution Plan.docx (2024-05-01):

| January 29th | February 5th | February 12th | February 19th | February 26th | March 4th | March 11th | March 18th | March 25th | April 1st | April 8th | April 15th
Finish Validating and Testing all Subsystems (ALL)
Order New PCB if Needed (ALL)
Order Ultrasonic Microphones and Speakers (ALL)
(Transmitter End) Connect/Validate Signal Amplifier and Filter (NC)
(Transmitter End) Connect/Validate Power Amplifier With Other Transmission Subsystems (NC)
(Transmitter End) Connect/Validate Frequency Modulator With Other Transmission Subsystems (NC)
(Receiver End) Connect/Validate Signal Amplifier and Filter (JR)
Connect/Validate Both Transmitter and Receiver Parts of Radio (ALL)
Final Validation and Testing of Radio (ALL)

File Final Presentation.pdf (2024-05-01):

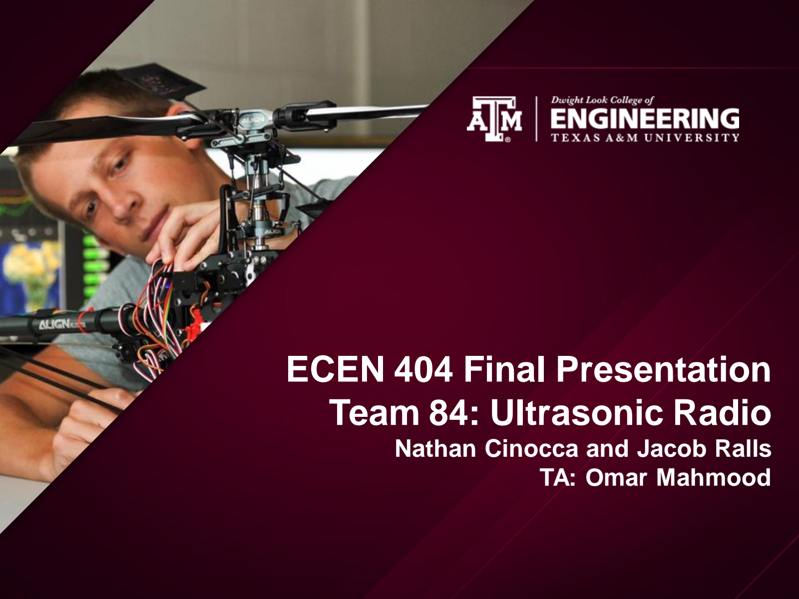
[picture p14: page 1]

# ECEN 404 Final Presentation Team 84: Ultrasonic Radio

### Nathan Cinocca and Jacob Ralls TA: Omar Mahmood

# Project Summary

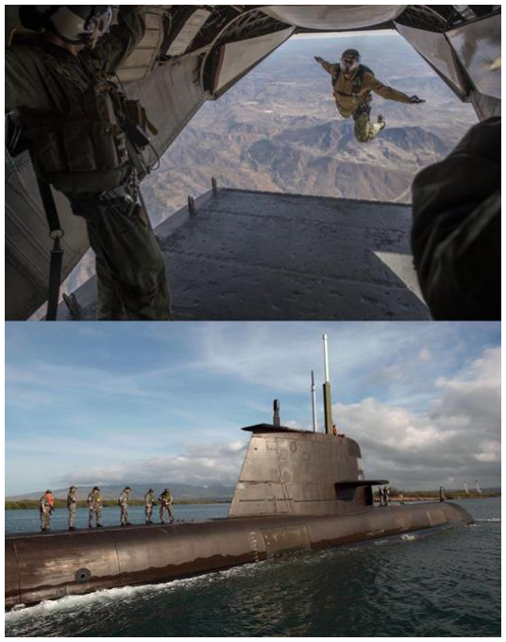
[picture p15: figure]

Problem statement:
- Communicating information is very important in almost every military operation. However, sometimes sending information through traditional methods is not feasible.
Solution proposal:
- A solution to this issue is to develop an acoustic ultrasonic radio.
– Acoustic waves and lower frequencies will limit
electromagnetic radiation
- This radio will allow for communications over relatively short distances.
- Communication will be slower than devices using electromagnetic waves

## Inegrated Project Diagram

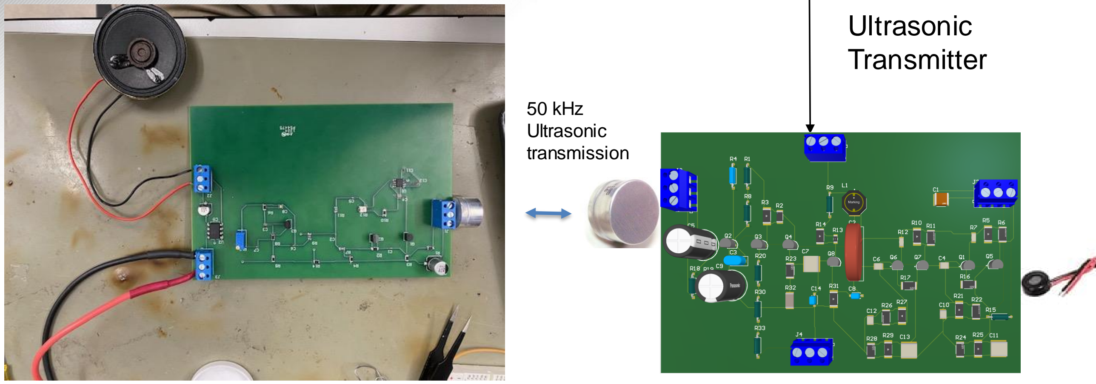
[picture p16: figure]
50 kHz Ultrasonic transmission; Ultrasonic Transmitter

- Input microphone covers human voice frequencies (100 Hz to 3 kHz)
- Voice is translated into an electrical signal
- Signal is amplified and filtered to enhance quality and eliminate unwanted noise
- Modulated to ultrasonic frequencies for transmission, with optional additional filtering
- Modulated signal goes through a power amplifier to achieve required gain
- Signal travels to receiving microphone for filtering and amplification for demodulation
- After demodulation, signal is filtered and output through a speaker within the human hearing range
- User uses R13 potentiometer as a volume adjuster of the output
- User uses R12 potentiometer as a means to filter input frequency ranges to be demodulated

Ultrasonic
Receiver

# Jacob Ralls

Designed, Tested, and Validated | Challenges Faced/Solutions Found
- Initially designed and tested individual working demodulator circuit • Designed and tested 4th Order Chebyshev Band Pass Filter • Designed and tested 2nd order Bessel filter design | • Prob: Band Pass Filter did not properly represent the gain shown in both LTSpice and Multisim simulations • Sol: Designed a simplified model with a focus on gain at a cost of bandwidth.

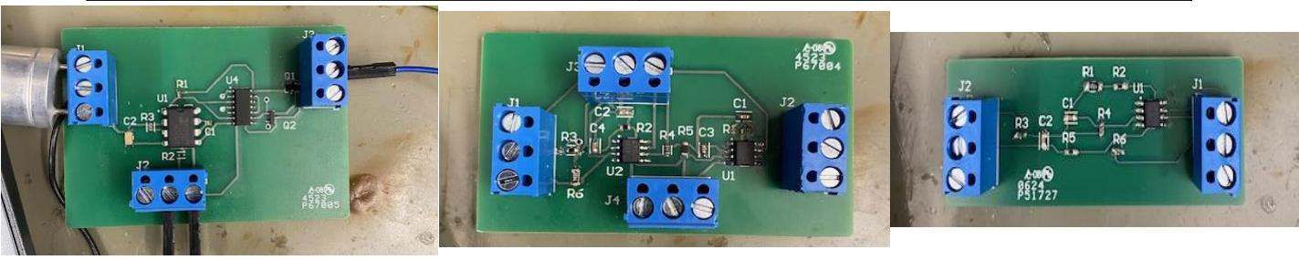
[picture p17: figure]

Working Demodulator
utilizing PLL circuit

Nonoptimal 4th Order
Chebyshev BPF

Ideal 2nd order Bessel
Filter

# Jacob Ralls

Designed, Tested, and Validated | Challenges Faced/Solutions Found
- Validated mass of overall system to be roughly 2.449 kg < 10 kg • Voltage input was tested to be lower than +9 VDC • Radio current level was found to be at most 0.306A validating the <0.9A requirement • Ultrasonic input mic able detect range low freq range (5Hz) and detect higher pitches (155Hz) | • Prob: Speaker output was unable to be heard from the required 15 meters away. • Soln: Designed new receiver PCB with adjustable output volume and reads wider input frequency range (Little over 500 kHz range while still being able to tune to lower ranges)

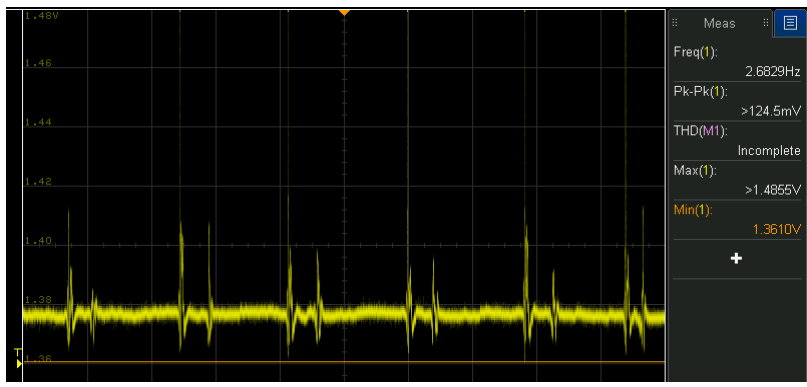
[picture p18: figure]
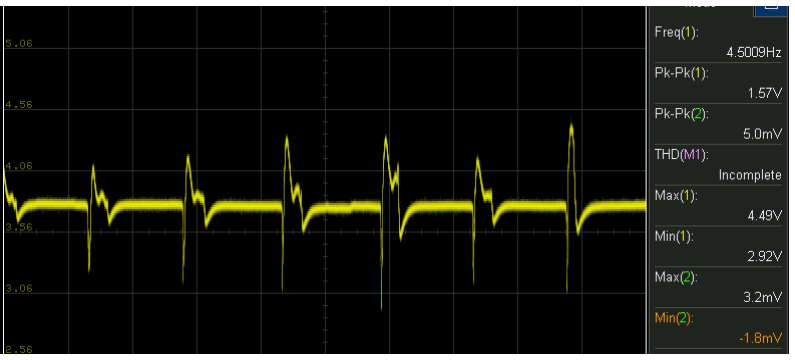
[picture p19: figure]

Mic Input Min Frequency | Speaker Output Min Frequency

# Jacob Ralls

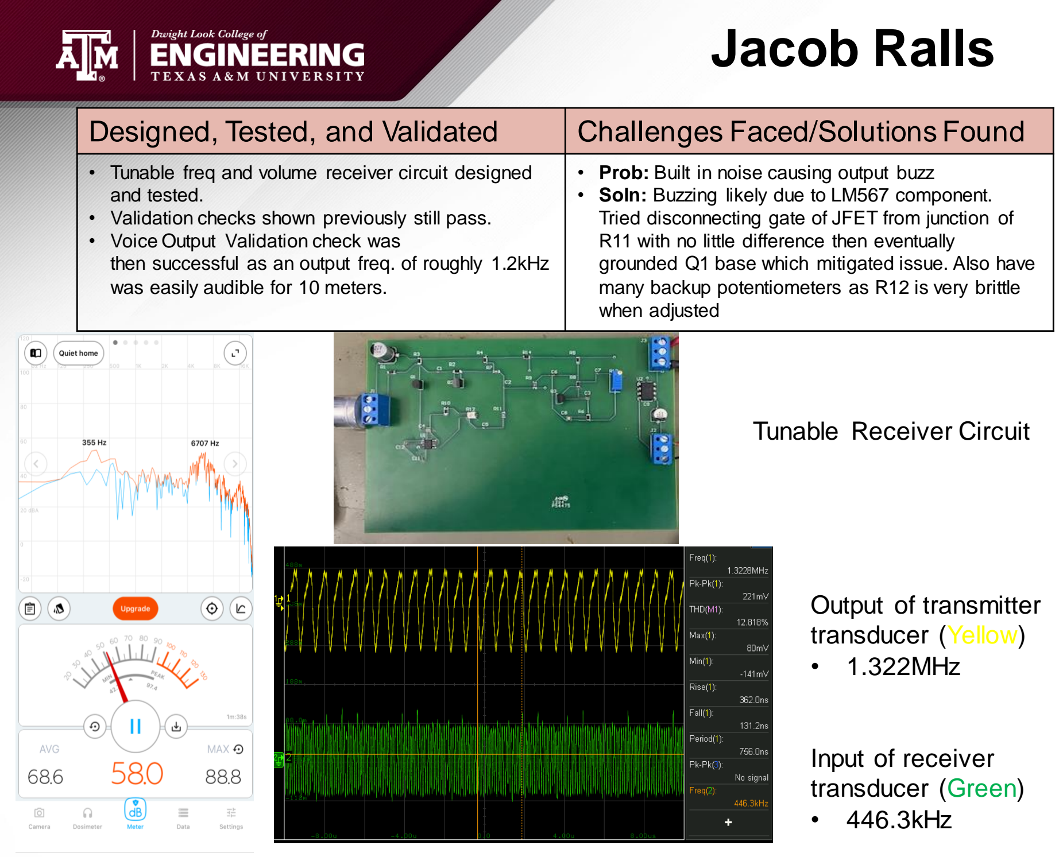
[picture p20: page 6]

Designed, Tested, and Validated | Challenges Faced/Solutions Found
- Tunable freq and volume receiver circuit designed and tested. • Validation checks shown previously still pass. • Voice Output Validation check was then successful as an output freq. of roughly 1.2kHz was easily audible for 10 meters. | • Prob: Built in noise causing output buzz • Soln: Buzzing likely due to LM567 component. Tried disconnecting gate of JFET from junction of R11 with no little difference then eventually grounded Q1 base which mitigated issue. Also have many backup potentiometers as R12 is very brittle when adjusted

Output of transmitter
transducer (Yellow)
- 1.322MHz

Input of receiver
transducer (Green)
- 446.3kHz

Tunable Receiver Circuit

# Nathan Cinocca

Designed, Tested, and Validated Challenges Faced/Solutions Found
- Initially designed and tested
individual frequency modulation
circuit
- Designed, tested, and validated low frequency filter
- Designed, tested, and validated signal amplifier
- Designed, tested, and validated power amplifier
- Prob: Frequency Modulator initially had too low of voltage to be properly tested or transmitted
- Sol: Designed a new frequency modulator that was able to transmit at a readable frequency

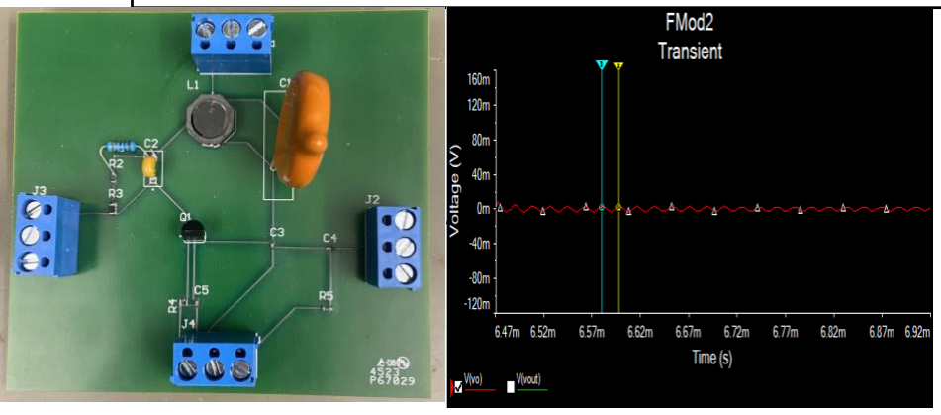
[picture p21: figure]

Original Low Voltage
Frequency Modulator

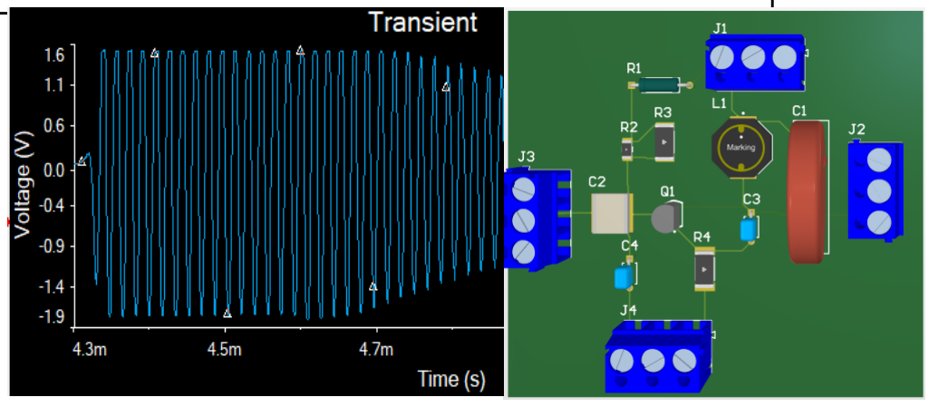
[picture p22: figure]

New High Voltage
Frequency Modulator

# Nathan Cinocca

Designed, Tested, and Validated | Challenges Faced/Solutions Found
- Voltage input was tested to be lower than +5 VDC • Current level was found to be at most 0.306A validating the <0.9A requirement • Ultrasonic input mic able detect range low frequencie range (5Hz) and detect higher pitches (155Hz) • When Transmitter side was tested with output transducer the transmission frequency was around 1.3 MHz | • Prob: The Transmission frequency was far too high upon original testing • Soln: Edited Modulator parameters and improved circuit connections to change transmission frequency back to 50kHz

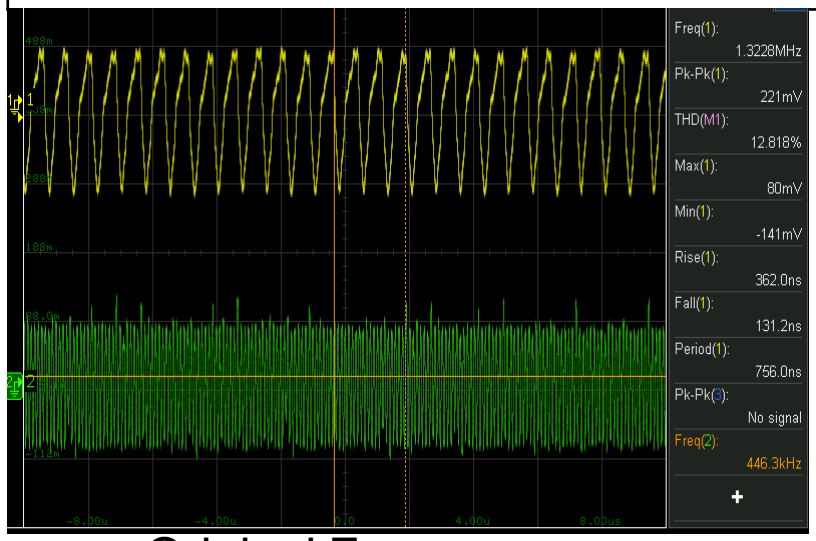
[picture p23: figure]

Original Frequency
Modulator Transmission

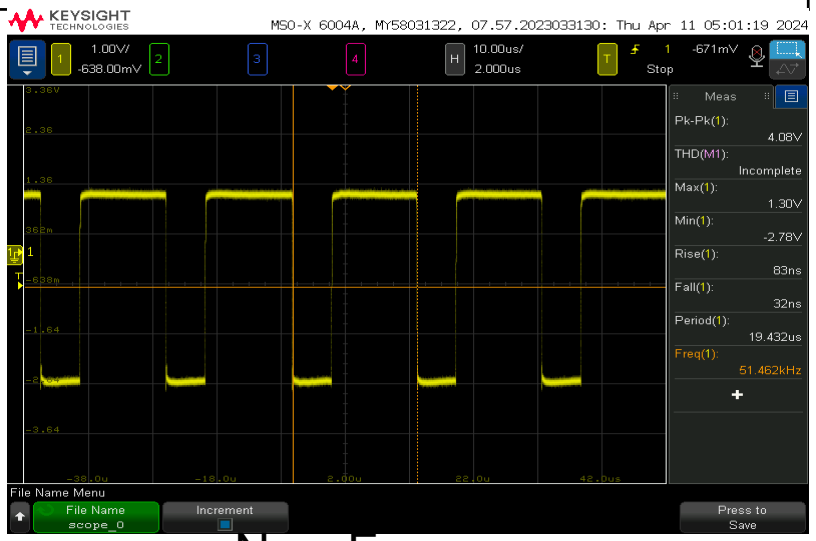
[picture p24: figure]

New Frequency
Modulator Transmission

# Integrated System Results

Task 1: User provides input through the mic. Successfully able to detect range of frequencies as low as 4.5 Hz


# Integrated System Results

Task 2: Signal then gets sent through the transmitter half of the circuit. Successfully transmits at around 50kHz.


# Integrated System Results

Task 3: Signal then gets
transmitted and received by the receiver. Not quite accurate as we are looking for a match between the two frequencies for a passed test and to effectively perform a proper transmission across the signals.


This process is the most notable failure within our system and is being heavily tested.

# Integrated System Results

Task 4: Received signal goes through the receiver process


- Due to the high amount of noise projected in the output of the circuit, it is difficult to deduce if proper demodulation is
occurring.
- This process is
currently deemed as an
unknown due to these noise levels.

# Integrated System Results

Task 5: Output of the signal gets projected through the speaker.


- Successfully able to output at a high enough volume at a recorded max of 88.8 decibels to be detectable at an acceptable range.
- This process is deemed as a success due to the output being audible from our selected 15 meters of distance while also being adjustable.

# Videos


# Conclusions

- As a result of challenges with model compatibility and complications regarding our sponsor's preferences, which have led to divergent deliverables and objectives, the design has been modified from the original specifications to operate as a one-way communication system, rather than the initially planned full-duplex bidirectional communication system.
- Some of our tests within our validation plan could be proven theoretically but the equipment used to test these, to our knowledge, were not readily available. I.e. a "container with high pressure" and "container with controlled humidity" for both the "Pressure (Altitude)" and "Humidity" tests respectively.
- Current status: Integration complete, however transmission process not fully validated, continued testing and debugging of pot rec circuit to cut noise to read input, integration/validation to be completed in 1 week

Thank you for your attention.

# Any questions?

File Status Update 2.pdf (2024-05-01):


# Team 84: Ultrasonic Radio Bi-Weekly Update 2

### Nathan Cinocca and Jacob Ralls Sponsor: Oscar Moreira-Tamayo TA: Omar Mahmood

# Project Summary


Problem statement:
- Communicating information is very important in almost every military operation. However, sometimes sending information through traditional methods is not feasible.
Solution proposal:
- A solution to this issue is to develop an acoustic ultrasonic radio.
– Acoustic waves and lower frequencies will limit
electromagnetic radiation
- This radio will allow for communications over relatively short distances.
- Communication will be slower than devices using electromagnetic waves

## Project/Subsystem Overview


•Input microphone covers human voice frequencies (100 Hz to 3 kHz)
•Voice is translated into an electrical signal
•Signal is amplified and filtered to enhance quality and eliminate unwanted noise •Modulated to ultrasonic frequencies for transmission, with optional additional filtering •Modulated signal goes through a power amplifier to achieve required gain
•Signal travels to receiving microphone for filtering and amplification for demodulation •After demodulation, signal is filtered and output through a speaker within the human hearing range

# Project Timeline

Subsystem
Designs and
Testing
(To complete
by 2/9)

Integration of
transmitter
subsystems
(to complete
by 2/26)

Integration of
receiver
subsystems
(to complete
by 2/26)

Final
Integration
(to complete
by 3/4)

System Test
(to complete
by 3/25)

Validation
(to complete
by 4/8)

Demo and
Report
(to complete
by 4/15)

# Signal Amplifier & High Freq Filter (Receiver)

Jacob Ralls

Accomplishments since last presentation 18 hrs of effort | Ongoing progress/problems and plans until the next presentation
- Verified issues with circuit • Simulated multiple ideal models • Created and ordered PCB | • Solder and test functionality • Will integrate with the demodulator with tests to be performed on the joint system


# Signal Amplifier & High Freq Filter (Receiver)


Jacob Ralls

# Demodulator (Receiver)

Jacob Ralls

Accomplishments since last presentation 4 hrs of effort | Ongoing progress/problems and plans until the next presentation
- Successfully tested and runs as expected since 403 | • Work on implementing this with the Signal Amp & Filter • Run tests to ensure integration process is successful


# Demodulator (Receiver)


Jacob Ralls

- On the scope screen the two square waves are stable (this indicates that they are locked)
- Voltage of the square wave is shifted approximately 90 degrees with respect to the reference frequency.

# Signal Amplifier (Transmitter)

Nathan Cinocca

Accomplishments since 403 7 hrs of effort | Ongoing progress/problems and plans until the next presentation
- Resoldered entire PCB • Tested system responses on multimeter | • Begin integration with other transmitter subsystems


# Signal Amplifier (Transmitter)

Nathan Cinocca

### - Signal amplifier had a peak gain of around 26 dBs centered at 1k Hz with 3 dB frequencies at 3.1k Hz and 300 Hz - The gain and operational frequencies are correctly placed according to simulations


# Low Frequency Filter (Transmitter)

Nathan Cinocca

Accomplishments since 403 7 hrs of effort | Ongoing progress/problems and plans until the next presentation
- Resoldered entire PCB • Retested system response on multimeter | • Continue testing and attempting to determine circuit issues • Order a new PCB if unable to fix issues



## - Frequency response of the low frequency filter shows a much lower gain than anticipated with a shape that

does not resemble a filter.

## - The response is also very noisy - These issues indicate that there may still be some part of the PCB incorrectly soldered

# Low Frequency Filter (Transmitter)

Nathan Cinocca

# Power Amplifier (Transmitter)

Nathan Cinocca

Accomplishments since 403 7 hrs of effort | Ongoing progress/problems and plans until the next presentation
- Resoldered entire PCB • Tested system responses on multimeter | • Begin integration with other transmitter subsystems


# Power Amplifier (Transmitter)


Nathan Cinocca
- The power amplifier has a maximum gain of about 68 dBs centered at 45 kHz
- The amplifier has 3 dB frequencies at approximately 60k Hz and 35 kHz
- The operation of the power amplifer is within expectation according to simulations

# Frequency Modulator (Transmitter)

Nathan Cinocca

Accomplishments since 403 3 hrs of effort | Ongoing progress/problems and plans until the next presentation
- Resoldered entire PCB • Tested system responses on multimeter | • Begin integration with other transmitter subsystems


# Frequency Modulator (Transmitter)


Nathan Cinocca

### - Frequency modulator modulates a 1k Hz signal to around 40k Hz - This frequency is within expectations from simulations

# Execution Plan


⬛ Completed ⬛ Pending ⬛ Not Started ⬛ Behind Schedule

# Validation Plan


Thank you for your attention.

# Any questions?

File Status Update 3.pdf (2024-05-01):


# Team 84: Ultrasonic Radio Bi-Weekly Update 3

### Nathan Cinocca and Jacob Ralls Sponsor: John Lusher TA: Omar Mahmood

# Project Summary


Problem statement:
- Communicating information is very important in almost every military operation. However, sometimes sending information through traditional methods is not feasible.
Solution proposal:
- A solution to this issue is to develop an acoustic ultrasonic radio.
– Acoustic waves and lower frequencies will limit
electromagnetic radiation
- This radio will allow for communications over relatively short distances.
- Communication will be slower than devices using electromagnetic waves

## Project/Subsystem Overview


•Input microphone covers human voice frequencies (100 Hz to 3 kHz)
•Voice is translated into an electrical signal
•Signal is amplified and filtered to enhance quality and eliminate unwanted noise •Modulated to ultrasonic frequencies for transmission, with optional additional filtering •Modulated signal goes through a power amplifier to achieve required gain
•Signal travels to receiving microphone for filtering and amplification for demodulation •After demodulation, signal is filtered and output through a speaker within the human hearing range

# Project Timeline

Subsystem
Designs and
Testing
(To complete
by 2/9)

Integration of
transmitter
subsystems
(to complete
by 2/26)

Integration of
receiver
subsystems
(to complete
by 2/26)

Final
Integration
(to complete
by 3/4)

System Test
(to complete
by 3/25)

Validation
(to complete
by 4/8)

Demo and
Report
(to complete
by 4/15)

# Jacob Ralls

Accomplishments since last update 25 hrs of effort | Ongoing progress/problems and plans until the next presentation
- Successfully soldered and tested Sig Amp & Freq Filter • Integrated Demodulator and Sig Amp & Filter | • ON-GOING testing of power subsystem when integrated with receiver components • Order PCBs with integrated receiver, transmitter, and power system systems.


# Jacob Ralls


# Nathan Cinocca

Accomplishments since last update 20 hrs of effort | Ongoing progress/problems and plans until the next presentation
- Fixed issues with filter and retested the circuit • Created integrated transmitter (filter, signal amplifier, modulator, and power amplifier) pcb | • Order PCBs with integrated receiver, transmitter, and power system systems. • Continue testing current transmitter and receiver pair.


# Nathan Cinocca


# Execution Plan


⬛ Completed ⬛ Pending ⬛ Not Started ⬛ Behind Schedule

# Validation Plan


Thank you for your attention.

# Any questions?

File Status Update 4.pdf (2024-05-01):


# Team 84: Ultrasonic Radio Bi-Weekly Update 4

### Nathan Cinocca and Jacob Ralls TA: Omar Mahmood

# Project Summary


Problem statement:
- Communicating information is very important in almost every military operation. However, sometimes sending information through traditional methods is not feasible.
Solution proposal:
- A solution to this issue is to develop an acoustic ultrasonic radio.
– Acoustic waves and lower frequencies will limit
electromagnetic radiation
- This radio will allow for communications over relatively short distances.
- Communication will be slower than devices using electromagnetic waves

Project/Subsystem Overview; 40 kHz; 25kHz

•Input microphone covers human voice frequencies (100 Hz to 3 kHz)
•Voice is translated into an electrical signal
•Signal is amplified and filtered to enhance quality and eliminate unwanted noise •Modulated to ultrasonic frequencies for transmission, with optional additional filtering
•Modulated signal goes through a power amplifier to achieve required gain
•Signal travels to receiving microphone for filtering and amplification for demodulation
•After demodulation, signal is filtered and output through a speaker within the human hearing range

# Project Timeline

Subsystem
Designs and
Testing
(To complete
by 2/9)

Integration of
transmitter
subsystems
(to complete
by 2/26)

Integration of
receiver
subsystems
(to complete
by 2/26)

Final
Integration
(to complete
by 3/4)

System Test
(to complete
by 3/25)

Validation
(to complete
by 4/8)

Demo and
Report
(to complete
by 4/15)

# Jacob Ralls

Accomplishments since last
update | 20 hrs of effort

Ongoing progress/problems and plans until the next presentation
- Power subsystem simulated and tested to be working (50
khz receiver PCB)
- Designed and finalized receiver PCB for varying freq from 1 Hz – 500 kHz
- Designed and finalized simplified 40 kHz Receiver PCB in case of 50 kHz PCB does not work with 40 kHz transducers
- Once parts received, test my current 50 khz amplifier and demodulator with transmitter components.
- If successful run error
tests through distance
measurements and barriers.

# Jacob Ralls


# Jacob Ralls


# Jacob Ralls


# Jacob Ralls


# Jacob Ralls


# Jacob Ralls


# Nathan Cinocca

Accomplishments since last
update | 14 hrs of
effort

Ongoing progress/problems and plans until the next presentation

- Modified filter design
- Finished PCB for 50kHz
transmitter
- Modified circuits to create 25kHz transmitter and finished the PCB for the transmitter
- Order PCBs with
integrated receiver, transmitter, and power system systems.
- Solder the new PCBs and test for functionality
- Test current transmitter and receiver pair.

# Nathan Cinocca


# Nathan Cinocca


# Nathan Cinocca


# Execution Plan


⬛ Completed ⬛ Pending ⬛ Not Started ⬛ Behind Schedule

# Validation Plan


Thank you for your attention.

# Any questions?

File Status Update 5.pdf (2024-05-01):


# Team 84: Ultrasonic Radio Bi-Weekly Update 5

### Nathan Cinocca and Jacob Ralls TA: Omar Mahmood

# Project Summary


Problem statement:
- Communicating information is very important in almost every military operation. However, sometimes sending information through traditional methods is not feasible.
Solution proposal:
- A solution to this issue is to develop an acoustic ultrasonic radio.
– Acoustic waves and lower frequencies will limit
electromagnetic radiation
- This radio will allow for communications over relatively short distances.
- Communication will be slower than devices using electromagnetic waves

Project/Subsystem Overview; 40 kHz; 25kHz

•Input microphone covers human voice frequencies (100 Hz to 3 kHz)
•Voice is translated into an electrical signal
•Signal is amplified and filtered to enhance quality and eliminate unwanted noise •Modulated to ultrasonic frequencies for transmission, with optional additional filtering
•Modulated signal goes through a power amplifier to achieve required gain
•Signal travels to receiving microphone for filtering and amplification for demodulation
•After demodulation, signal is filtered and output through a speaker within the human hearing range

# Project Timeline

Subsystem
Designs and
Testing
(To complete
by 2/9)

Integration of
transmitter
subsystems
(to complete
by 2/26)

Integration of
receiver
subsystems
(to complete
by 2/26)

Final
Integration
(to complete
by 3/4)

System Test
(to complete
by 3/25)

Validation
(to complete
by 4/8)

Demo and
Report
(to complete
by 4/15)

# Jacob Ralls

Accomplishments since last
update | 25 hrs of effort

Ongoing progress/problems and plans until the next presentation
- Tested integrated receiver components with transmitted components (Transducer was making high pitched sound on transmitter end)
- Aided in resolving issue with the demodulator (Was only showing DC voltage gain)
- Tested and Validated
compatibility between the
speaker and microphone
- Tested FM with the power amplifier (showed increase in voltage but did not show faster frequency)
- ONGOING working compatibility of modulator and demodulator
- Once received, solder and test new demodulated circuit utilizing the potentiometer to control voltage in the VCO (Likely current issue with the communication between systems)
- Validate other tasks once compatibility works.

# Nathan Cinocca

Accomplishments since last
update | 25 hrs of
effort

Ongoing progress/problems and plans until the next presentation

- Fixed issue with frequency modulator
- Tested and validated the transmitter side of the radio (microphone picked up voice input, was amplified, modulated, and sent through the 50k Hz speaker)
- Tested and validated the functionality of the speakers and microphones
- Finish validating the
communication issue between the modulator and demodulator
- Test slightly new frequency modulator if necessary
- Order, solder, and test final PCB once modulation/demodulation issue is resolved



# Jacob Ralls


# Jacob Ralls



# Execution Plan


⬛ Completed ⬛ Pending ⬛ Not Started ⬛ Behind Schedule

# Validation Plan


Thank you for your attention.

# Any questions?

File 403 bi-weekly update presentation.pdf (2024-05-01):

# Team: #84 Ultrasonic Radio

Amplifier and Filter
Frequency Modulator
Filter and Power Amplifier
Frequency Demodulator
Amplifier and Filter
Transmitter/ Receiver
Filter and Output Voice

The ultrasonic radio's input microphone covers human voice frequencies (100 Hz to 3 kHz), translating voice into an electrical signal. This signal is amplified and filtered to enhance its quality and eliminate unwanted noise. Next, it's modulated to ultrasonic frequencies for transmission, with optional additional filtering. The modulated signal goes through a power amplifier to achieve the required gain, then travels to the receiving microphone, where it's filtered and amplified for demodulation. After demodulation, it's filtered and output through a speaker within the human hearing range.

Nathan | Nathan | Nathan
Nathan/Jacob | Jacob | Jacob | Jacob

# Team: #84 Ultrasonic Radio


Accomplishments since the last presentation 40 hrs | Ongoing progress/problems and plans until the next presentation
- Designed, Simulated, and Tested Signal Amplifier • Design and Simulated Low Frequency Filter • Created Design for Frequency Modulator | • Signal Amplifier gain is low • Planning to do more work on Modulator and Power Amplifier • Practice with Altium for PCB

Signal Amplifier/Low Frequency Filter/Frequency Modulator Nathan Cinocca

## Signal Amplifier, High Frequency Filter, Demodulator Jacob Ralls


Accomplishments since the last presentation 40 hrs | Ongoing progress/problems and plans until the next presentation
- Designed, Simulated, and Tested 4th Order Chebyshev Bandpass Filter • FM Demodulation Design using PPL Created | • Issue with noisy lower frequencies for the bandpass filter • Simulations and Testing for the Demodulator • Designing of Altium board with progress

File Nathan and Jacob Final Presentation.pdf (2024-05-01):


# Project name: Ultrasonic Radio Team members: Nathan Cinocca Jacob Ralls

# Project description


## Problem statement: - Communicating information is very important in almost

every military operation.

## However, sometimes sending information through traditional methods

is not feasible.
- For example,

## electromagnetic waves can interfere with airplane or submarine equipment

which can cause accidents.

# Project description

# Solution proposal: - A solution to this issue is to


# develop an acoustic

ultrasonic radio.

## – Acoustic waves and lower frequencies will limit electromagnetic radiation

# - This radio will allow for two-way communications over

relatively short distances.

# - Communication will be slower than devices using electromagnetic waves

## System Breakdown


# Signal Amplifier and High Frequency Filter Jacob Ralls

### Overall Accomplishments


- Designed and Simulated 4th Order Chebyshev Bandpass Filter through Multisim
- Tested the constructed Bandpass Filter on a Breadboard
- Moved design to Altium Design
- From here created and ordered the Bandpass Filter PCB
- All parts have been ordered and shipped
Freq | Gain
36.49k | 5.65
44.72k | 5.75
54.81k | 6.41
67.18k | 12.1
82.33k | 17.39
100.9k | 24.32
123.7k | 23.04
151.6k | 15.72
185.8k | 11.86
227.7k | 8.91
279.0k | 3.62

# Signal Amplifier and High Frequency Filter Jacob Ralls


# Demodulator Jacob Ralls

### Overall Accomplishments

- Designed and Simulated Demodulator using a Phase Locked Loop (First Isolated the Voltage to Frequency Converter then looked at complete PLL Design)
- Moved design to Altium Design
- From here created and ordered the Bandpass Filter PCB
- All parts have been ordered and shipped


# Demodulator Jacob Ralls


# Signal Amplifier and Filter Nathan Cinocca

### Overall Accomplishments

- Designed and Simulated Low Frequency Filter through Multisim
- Designed and Simulated Signal Amplifier through Multisim
- Tested Signal Amplifier
- Moved design to Altium Design
- Created PCB for both the signal amplifier and the filter


Signal Amplifier | Filter


# Power Amplifier and Modulator Nathan Cinocca

### Overall Accomplishments

- Designed and Simulated Power Amplifier through Multisim
- Designed and Frequency Modulator through Multisim
- Moved design to Altium Design
- Created PCB for both the power amplifier and the frequency modulator


Frequency Modulator | Power Amplifier


# Remaining Tasks – Jacob Ralls

# - PCBs need to be delivered - Solder all components onto the PCBs

- Test circuits using Multimeter,

# Oscilloscope (via transient response or AC response depending on function to be tested) - Video Demo successful outcome

# Remaining Tasks – Nathan Cinocca

# - PCBs need to be ordered and delivered - Solder all components onto the PCBs

- Test circuits using Multimeter,

# Oscilloscope (via transient response or AC response depending on function to be tested) - Video Demo successful outcome

# Execution Plan


# Validation Plan


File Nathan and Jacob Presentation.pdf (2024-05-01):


### Project name: Ultrasonic Radio Team members: Nathan Cinocca Jacob Ralls

### Project description


Problem statement:
- Communicating information is very important in almost every military operation.
However, sometimes
sending information
through traditional methods is not feasible.
- For example,
electromagnetic waves can
interfere with airplane or submarine equipment
which can cause accidents.

### Project description

Solution proposal:
- A solution to this issue is to develop an acoustic
ultrasonic radio.
– Acoustic waves and lower frequencies will limit
electromagnetic radiation
- This radio will allow for two-way communications over
relatively short distances.
- Communication will be
slower than devices using
electromagnetic waves


System Breakdown

### Signal Amplifier


- Signal Amplifier will
increase the strength of
signals to improve
transmission and reception
- Signal Amplifier will be transistor based using
2N3904 and 2N3906 NPN
and PNP transistors
- The Amplifier will use 5 volts and <= 50 mA
- I have begun designing the amplifier using multisim

### Filters

- Multiple filters will be used for this radio, but all will be band pass filters
- Pass bands will vary depending on placement in circuit
– Voice filters 100-300 Hz
– Transmitting filter 50 kHz
– Receiving filter 60 kHz
- Filters should help to reduce noise
- Use op amp LM741CN


### Frequency Modulation/Demodulation

### - Information will be transmitted after applying frequency modulation

– Signal will be modulated to the ultrasonic frequencies of the transducers

### - Creating the modulator using op amp LM741CN

### Power Amplifier

- Power Amplifier will allow for increased transmission distance
– Roughly 50 feet
- Very large gain of around 100 dB
- The power amplifier will be used right before transmission
- The Amplifier will be transistor based using FMMT415 Transistors
– 500 mA current limit


### Validation/Execution plan

Currently: have outlined basic functions of systems, selected some parts, and begun signal amplifier design

| October 6th | October 20th | November 3rd | November 17th | December 1st
Signal Amplifier | Design, simulate, and do basic testing | None | None | None | Final testing
Filters | Begin design and simulations | Test filters | None | None | Final testing
Frequency Modulation/ Demodulation | Do additional research | Begin designing and Simulating Modulator | Test modulator and design demodulator | Simulate and test demodulator | Final testing
Power Amplifier | Do additional research | Research and designing | Begin simulations | Test power amplifier | Final testing

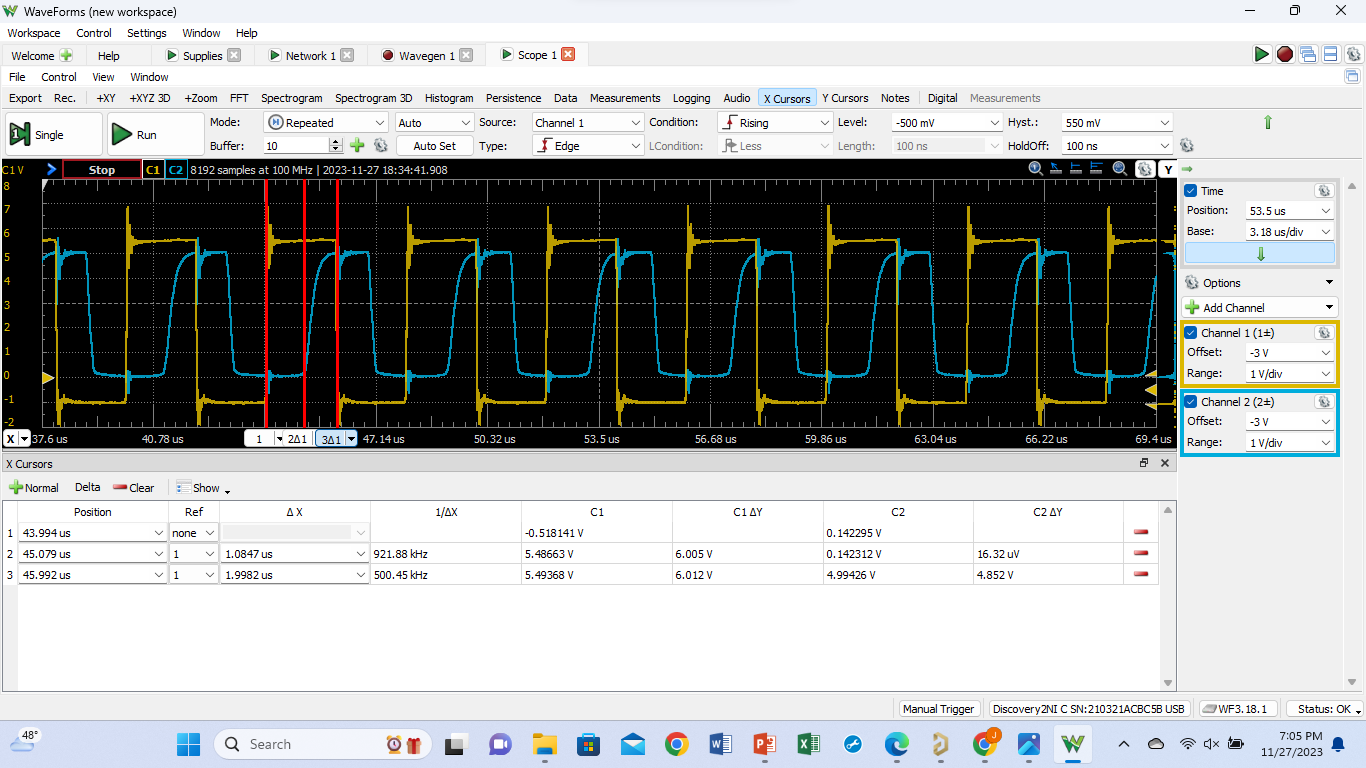
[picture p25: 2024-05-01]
Demodulated output.png

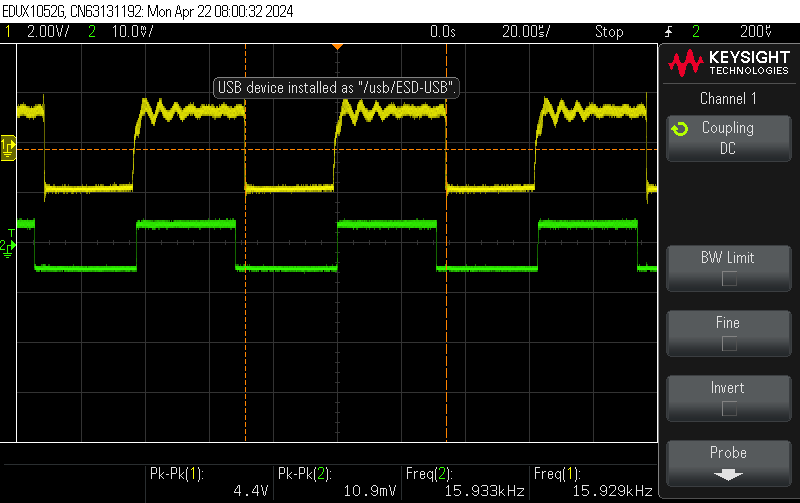
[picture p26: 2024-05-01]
SundayBeforeDemoSS.png

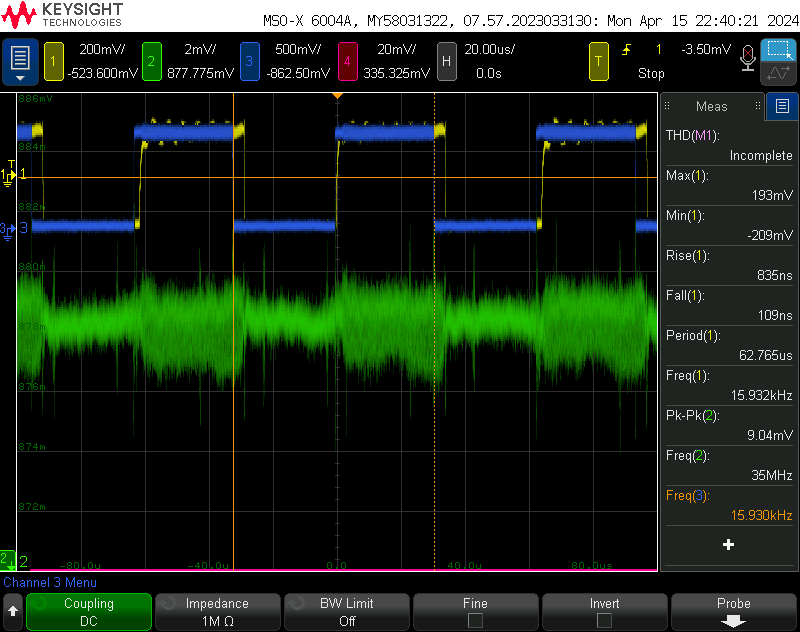
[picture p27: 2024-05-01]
YTransBlR12GrRec.png

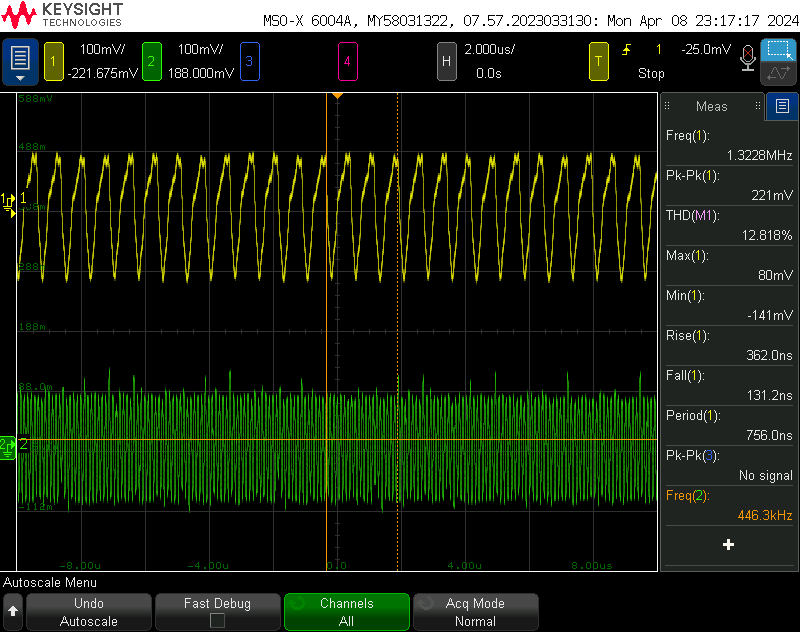
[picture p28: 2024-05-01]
Costant sound wave.png

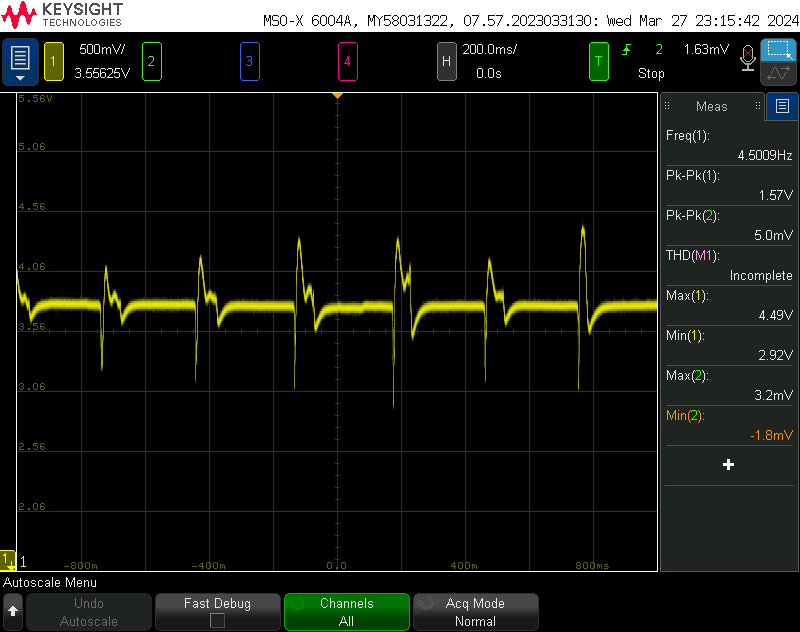
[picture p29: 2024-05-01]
Tapping input.png

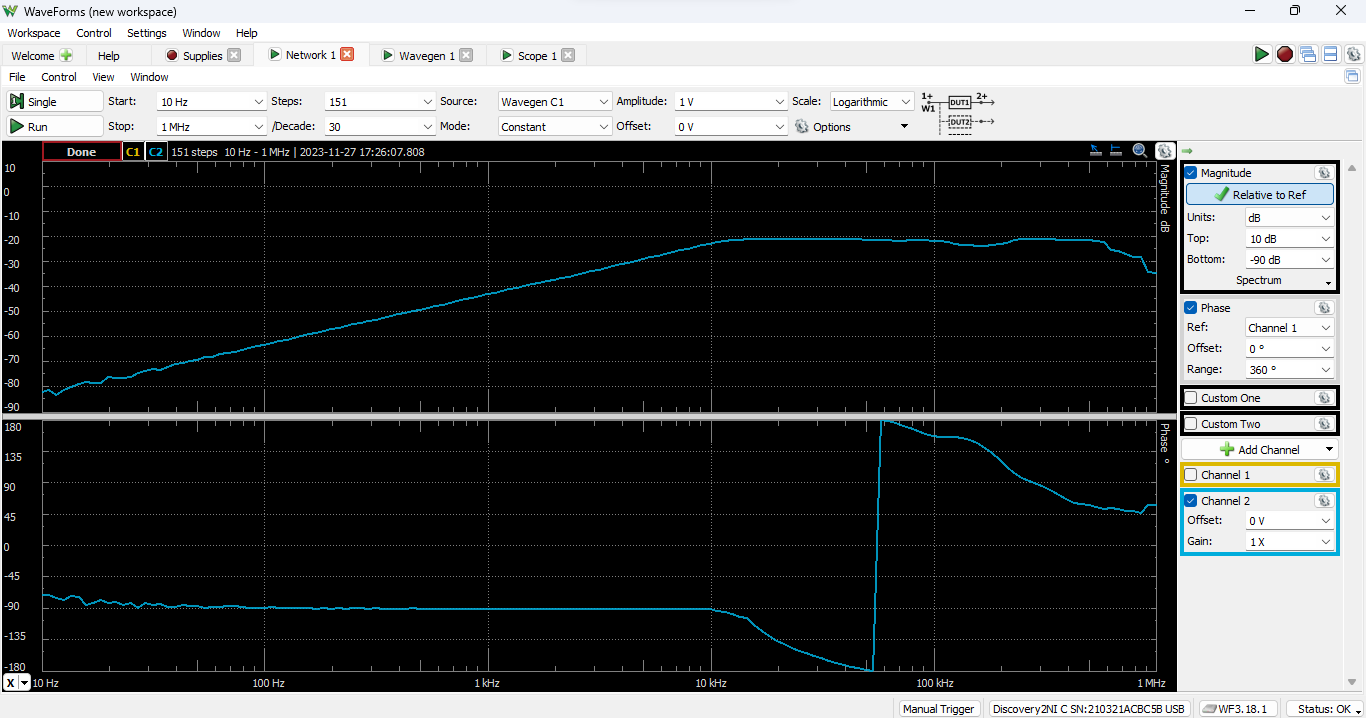
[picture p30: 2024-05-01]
Another Bodeplot for BPF.png

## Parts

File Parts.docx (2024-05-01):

Parts

Looking into potential sensors/microphones

https://www.ti.com/sensors/specialty-sensors/ultrasonic/products.html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

Filter: 40 kHz min

Looking into potential op amps

https://www.ti.com/product/LME49743

Filter GBW: 30 MHz

OPA817

Look into VCOs for demodulators:

NE555

PLLs:

CD4046B PLL

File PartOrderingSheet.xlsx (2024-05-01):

Order Date | Part Number | Item Name | Location to Buy From | Cost per Part | Quantity | Total Cost | Item Description
2023-11-07 | 06036D106MAT2A | 10uF Cap | Mouser | $0.16 | 1 | $0.16 | Multilayer Ceramic Capacitors MLCC - SMD/SMT 6.3V 10uF X5R 0603 20%
2023-11-07 | 12105C474JAT2A | 470nF Cap | Mouser | $0.45 | 4 | $1.80 | Multilayer Ceramic Capacitors MLCC - SMD/SMT 50V 0.47uF X7R 1210 5%
2023-11-07 | 04024D105KAT2A | 1uF Cap | Mouser | $0.37 | 2 | $0.74 | Multilayer Ceramic Capacitors MLCC - SMD/SMT 4V 1uF X5R 0402 0.1
2023-11-07 | 691101710003 | Connector/Terminal Block | Mouser | $1.03 | 16 | $16.48 | Fixed Terminal Blocks WR-TBL 250VAC 16A 3P Straight
2023-11-07 | 2N3904BU | NPN Bipoloar Transistor | Mouser | $0.35 | 8 | $2.80 | Bipolar (BJT) Transistor NPN 40 V 200 mA 300MHz 625 mW Through Hole TO-92-3
2023-11-07 | MCT06030D3301BP100 | 3.3k Ohm Resistor | Mouser | $0.73 | 2 | $1.46 | Thin Film Resistors - SMD MCT 0603-25 0.1% P1 3K3
2023-11-07 | MRS25000C1001FCT00 | 1k Ohm Resistor | Mouser | $0.29 | 23 | $6.67 | Metal Film Resistors - Through Hole .6watt 1Kohms 1%
2023-11-07 | RK73B2BTTD201J | 200 Ohm Resistor | Mouser | $0.10 | 4 | $0.40 | Thick Film Resistors - SMD 1/4watts 200ohms 5%
2023-11-07 | 565R30GASS33 | 33nF Cap | Mouser | $3.51 | 1 | $3.51 | Ceramic Disc Capacitors 0.033uF 3Kvolts 20%
2023-11-07 | C333C105M5U5TA | 1uF Cap | Mouser | $0.41 | 1 | $0.41 | Multilayer Ceramic Capacitors MLCC - Leaded 50V 1uF Z5U 20% LS=5.08mm
2023-11-07 | 0402YC102JAT2A | 1nF Cap | Mouser | $0.10 | 3 | $0.30 | Multilayer Ceramic Capacitors MLCC - SMD/SMT 16V 1000pF X7R 0402 5%
2023-11-07 | 744065221 | 220 uH Inductor | Mouser | $1.58 | 1 | $1.58 | Power Inductors - SMD WE-TPC 1028 220uH .5A 750mOhm
2023-11-07 | CRCW02013K30JNED | 3.3k Ohm Resistor | Mouser | $0.10 | 1 | $0.10 | Thick Film Resistors - SMD 1/20watt 3.3Kohms 1% 200ppm
2023-11-07 | CRCW060310K0FKTB | 10k Ohm Resistor | Mouser | $0.20 | 2 | $0.40 | Thick Film Resistors - SMD 1/10watt 10Kohms 1%
2023-11-07 | CRCW080520K0FKEB | 20k Ohm Resistor | Mouser | $0.10 | 1 | $0.10 | Thick Film Resistors - SMD 1/8watt 20Kohms 1%
2023-11-07 | RG1005P-152-D-T10 | 1.5k Ohm Resistor | Mouser | $0.15 | 1 | $0.15 | Thin Film Resistors - SMD 1/16W 1.5K Ohms 0.5% 0402 25ppm
2023-11-07 | EEUED2W100 | 10uF Cap | Mouser | $1.07 | 3 | $3.21 | Aluminum Electrolytic Capacitors - Radial Leaded 10uF 450volts AEC-Q200
2023-11-07 | RDER71H104K0M1H03A | .1uF Cap | Mouser | $0.40 | 1 | $0.40 | Multilayer Ceramic Capacitors MLCC - Leaded .1UF 50V 10% 5.0MM
2023-11-07 | MRS25000C1000FRP00 | 100 Ohm Resistor | Mouser | $0.13 | 18 | $2.32 | Metal Film Resistors - Through Hole .6watts 100ohms 1%
2023-11-07 | UA741CP | 741 op amp | Mouser | $0.44 | 1 | $0.44 | Operational Amplifiers - Op Amps GP Op Amp
2023-11-07 | RDER73A473K4K1H03B | 47 nF cap | Mouser | $0.84 | 1 | $0.84 | Multilayer Ceramic Capacitors MLCC - Leaded
2023-11-07 | MRS25000C1101FCT00 | 1.1k Ohm Resistor | Mouser | $0.29 | 1 | $0.29 | Metal Film Resistors - Through Hole .6watt 1.1Kohms 1%
2023-11-07 | MRS25000C5620FRP00 | 562 Ohm resistor | Mouser | $0.29 | 2 | $0.58 | Metal Film Resistors - Through Hole .6watt 562ohms 1%
 |  |  |  |  |  | $45.14
PCBs (Advanced Circuits is the Vendor)
Order Date | Part # | Revision # | X dimensions (inches) | Y (dimensions inches) | Solder Mask | Silkscreen | Quantity
2023-11-07 | SignalAmplifierPCB | 0 | 4.455 | 3.835 | Both | Top | 1
2023-11-07 | Low_Frequency_Filter_PCB | 0 | 3.755 | 3.095 | Both | Top | 1
2023-11-07 | FrequencyModulatorPCB | 0 | 3.43 | 3.15 | Both | Top | 1
2023-11-07 | PowerAmplifierPCB | 0 | 4.335 | 3.07 | Both | Top | 1

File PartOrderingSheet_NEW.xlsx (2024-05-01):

Order Date | Part Number | Item Name | Location to Buy From | Cost per Part | Quantity | Total Cost | Item Description
2024-04-01 | C2220C106K3RACAUTO | 10uF Cap | Mouser | $3.80 | 1 | $3.80 | Multilayer Ceramic Capacitors MLCC - SMD/SMT 25V 10uF X7R 2220 10% AEC-Q200
2024-04-01 | 565R30GASS33 | 0.033uF Cap | Mouser | $3.50 | 2 | $7.00 | eramic Disc Capacitors 0.033uF 3Kvolts 20%
2024-04-01 | RDER73A473K4K1H03B | 0.047uF Cap | Mouser | $1.07 | 1 | $1.07 | Multilayer Ceramic Capacitors MLCC - Leaded .047UF 1000V 10% 5.0MM
2024-04-01 | CAP 470nF 50V 1210(3225) | 0.47uF Cap | Mouser | $1.31 | 4 | $5.24 | Multilayer Ceramic Capacitors MLCC - SMD/SMT .47uF 50volts X7R 5%
2024-04-01 | EEUED2W100 | 10 uF CAP | Mouser | $0.96 | 2 | $1.92 | Aluminum Electrolytic Capacitors - Radial Leaded 10uF 450V 105C 20%
2024-04-01 | CAP 1uF 100V 2225(5664) | 1uF Cap | Mouser | $4.07 | 4 | $16.28 | Multilayer Ceramic Capacitors MLCC - SMD/SMT 100volts 1uF 10% X7R AUTO
2024-04-01 | RCE5C1H102J0M1H03A | 1000pF Cap | Mouser | $0.42 | 4 | $1.68 | Multilayer Ceramic Capacitors MLCC - Leaded
2024-04-01 | 691101710003 | connector | Mouser | $1.03 | 8 | $8.24 | Fixed Terminal Blocks WR-TBL 250VAC 16A 3P Straight
2024-04-01 | 744065221 | 220uH Ind | Mouser | $1.65 | 2 | $3.30 | Power Inductors - SMD WE-TPC 1028 220uH .5A 750mOhm
2024-04-01 | 2N3904 | npn BJT | Mouser | $0.10 | 9 | $0.90 | Bipolar Transistors - BJT BJT, TO-92, 40V, 200mA, NPN
2024-04-01 | MRS25000C1001FCT00 | 1k res | Mouser | $0.29 | 6 | $1.74 | Metal Film Resistors - Through Hole .6watt 1Kohms 1%
2024-04-01 | CRCW2010750RFKEF | 750 res | Mouser | $0.26 | 1 | $0.26 | Thick Film Resistors - SMD 3/4watt 750ohms 1%
2024-04-01 | CRCW25121K00JNEG | 1k res | Mouser | $0.32 | 7 | $2.24 | Thick Film Resistors - SMD 1watt 1Kohms 5%
2024-04-01 | MRS25000C1101FCT00 | 1.1k res | Mouser | $0.29 | 1 | $0.29 | Metal Film Resistors - Through Hole .6watt 1.1Kohms 1%
2024-04-01 | CR2512-JW-471ELF | 470 res | Mouser | $0.10 | 4 | $0.40 | Thick Film Resistors - SMD 470OHM 1WATT 5%
2024-04-01 | RK73B2BTTD332J | 3.3k res | Mouser | $0.10 | 2 | $0.20 | Thick Film Resistors - SMD 1/4watts 3.3Kohms 5%
2024-04-01 | MCA1206MD1003BP100 | 100k res | Mouser | $1.07 | 2 | $2.14 | Thin Film Resistors - SMD 1/4W 100Kohms 0.1% 1206 25ppm Auto
2024-04-01 | CRCW251247K0FKEG | 47k res | Mouser | $0.32 | 2 | $0.64 | Thick Film Resistors - SMD 1 watt 47Kohms 1% 100ppm
2024-04-01 | RMCF2512JT200R | 200 res | Mouser | $0.22 | 5 | $1.10 | Thick Film Resistors - SMD 200Ohms 2512 1W 5% Std Power AEC-Q200
2024-04-01 | MRS25000C5620FRP00 | 562 res | Mouser | $0.28 | 2 | $0.56 | Metal Film Resistors - Through Hole .6watt 562ohms 1%
2024-04-01 | MRS25000C1000FRP00 | 100 res | Mouser | $0.22 | 2 | $0.44 | Metal Film Resistors - Through Hole .6watts 100ohms 1%
2024-04-01 | CRCW25121K50FKEG | 1.5k res | Mouser | $0.34 | 2 | $0.68 | Thick Film Resistors - SMD 1watt 1.5Kohms 1%
2024-04-01 | 150R 1% 2512(6432) | 150 res | Mouser | $0.59 | 1 | $0.59 | Thick Film Resistors - SMD CRGP 2512 150R 1% SMD Resistor
2024-04-01 | CMEJ-0706-42-P | electret mic | Mouser | $0.71 | 2 | $1.42 | Microphones microphone, 7 mm, electret condenser, omnidirectional, Pin, 2 Vdc, 42 dB sensitivity
2023-11-07 | 06036D106MAT2A | 10uF Cap | Mouser | $0.16 | 1 | $0.16 | Multilayer Ceramic Capacitors MLCC - SMD/SMT 6.3V 10uF X5R 0603 20%
2023-11-07 | 12105C474JAT2A | 470nF Cap | Mouser | $0.45 | 4 | $1.80 | Multilayer Ceramic Capacitors MLCC - SMD/SMT 50V 0.47uF X7R 1210 5%
2023-11-07 | 04024D105KAT2A | 1uF Cap | Mouser | $0.37 | 2 | $0.74 | Multilayer Ceramic Capacitors MLCC - SMD/SMT 4V 1uF X5R 0402 0.1
2023-11-07 | 691101710003 | Connector/Terminal Block | Mouser | $1.03 | 16 | $16.48 | Fixed Terminal Blocks WR-TBL 250VAC 16A 3P Straight
2023-11-07 | 2N3904BU | NPN Bipoloar Transistor | Mouser | $0.35 | 8 | $2.80 | Bipolar (BJT) Transistor NPN 40 V 200 mA 300MHz 625 mW Through Hole TO-92-3
2023-11-07 | MCT06030D3301BP100 | 3.3k Ohm Resistor | Mouser | $0.73 | 2 | $1.46 | Thin Film Resistors - SMD MCT 0603-25 0.1% P1 3K3
2023-11-07 | MRS25000C1001FCT00 | 1k Ohm Resistor | Mouser | $0.29 | 23 | $6.67 | Metal Film Resistors - Through Hole .6watt 1Kohms 1%
2023-11-07 | RK73B2BTTD201J | 200 Ohm Resistor | Mouser | $0.10 | 4 | $0.40 | Thick Film Resistors - SMD 1/4watts 200ohms 5%
2023-11-07 | 565R30GASS33 | 33nF Cap | Mouser | $3.51 | 1 | $3.51 | Ceramic Disc Capacitors 0.033uF 3Kvolts 20%
2023-11-07 | C333C105M5U5TA | 1uF Cap | Mouser | $0.41 | 1 | $0.41 | Multilayer Ceramic Capacitors MLCC - Leaded 50V 1uF Z5U 20% LS=5.08mm
2023-11-07 | 0402YC102JAT2A | 1nF Cap | Mouser | $0.10 | 3 | $0.30 | Multilayer Ceramic Capacitors MLCC - SMD/SMT 16V 1000pF X7R 0402 5%
2023-11-07 | 744065221 | 220 uH Inductor | Mouser | $1.58 | 1 | $1.58 | Power Inductors - SMD WE-TPC 1028 220uH .5A 750mOhm
2023-11-07 | CRCW02013K30JNED | 3.3k Ohm Resistor | Mouser | $0.10 | 1 | $0.10 | Thick Film Resistors - SMD 1/20watt 3.3Kohms 1% 200ppm
2023-11-07 | CRCW060310K0FKTB | 10k Ohm Resistor | Mouser | $0.20 | 2 | $0.40 | Thick Film Resistors - SMD 1/10watt 10Kohms 1%
2023-11-07 | CRCW080520K0FKEB | 20k Ohm Resistor | Mouser | $0.10 | 1 | $0.10 | Thick Film Resistors - SMD 1/8watt 20Kohms 1%
2023-11-07 | RG1005P-152-D-T10 | 1.5k Ohm Resistor | Mouser | $0.15 | 1 | $0.15 | Thin Film Resistors - SMD 1/16W 1.5K Ohms 0.5% 0402 25ppm
2023-11-07 | EEUED2W100 | 10uF Cap | Mouser | $1.07 | 3 | $3.21 | Aluminum Electrolytic Capacitors - Radial Leaded 10uF 450volts AEC-Q200
2023-11-07 | RDER71H104K0M1H03A | .1uF Cap | Mouser | $0.40 | 1 | $0.40 | Multilayer Ceramic Capacitors MLCC - Leaded .1UF 50V 10% 5.0MM
2023-11-07 | MRS25000C1000FRP00 | 100 Ohm Resistor | Mouser | $0.13 | 18 | $2.32 | Metal Film Resistors - Through Hole .6watts 100ohms 1%
2023-11-07 | UA741CP | 741 op amp | Mouser | $0.44 | 1 | $0.44 | Operational Amplifiers - Op Amps GP Op Amp
2023-11-07 | RDER73A473K4K1H03B | 47 nF cap | Mouser | $0.84 | 1 | $0.84 | Multilayer Ceramic Capacitors MLCC - Leaded
2023-11-07 | MRS25000C1101FCT00 | 1.1k Ohm Resistor | Mouser | $0.29 | 1 | $0.29 | Metal Film Resistors - Through Hole .6watt 1.1Kohms 1%
2023-11-07 | MRS25000C5620FRP00 | 562 Ohm resistor | Mouser | $0.29 | 2 | $0.58 | Metal Film Resistors - Through Hole .6watt 562ohms 1%
 |  |  |  |  |  | $107.27
PCBs (Advanced Circuits is the Vendor)
Order Date | Part # | Revision # | X dimensions (inches) | Y (dimensions inches) | Solder Mask | Silkscreen | Quantity
2024-04-01 | New_ModulatorPCB | 0 | 2.815 | 2.62 | Both | Top | 1
2024-04-01 | Final_TransmitterPCB | 0 | 6 | 4 | Both | Top | 1
2023-11-07 | SignalAmplifierPCB | 0 | 4.455 | 3.835 | Both | Top | 1
2023-11-07 | Low_Frequency_Filter_PCB | 0 | 3.755 | 3.095 | Both | Top | 1
2023-11-07 | FrequencyModulatorPCB | 0 | 3.43 | 3.15 | Both | Top | 1
2023-11-07 | PowerAmplifierPCB | 0 | 4.335 | 3.07 | Both | Top | 1

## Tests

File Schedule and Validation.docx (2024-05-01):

Ultrasonic Radio

Nathan Cinocca

Schedule and Validation

REVISION – Draft

28 September 2023

Schedule

| October 2nd | October 9th | October 16th | October 23th | October 30th | November 6th | November 13th | November 20th
Design and simulate signal amplifier
Power Amplifier Research
Modulation/demodulation Research
Order Parts
Filter Design
Signal Amplifier Test
Design and simulate modulation/demodulation
Power Amplifier Design
Filter Test (For Modulation)
Filter Test (For Demodulation)
Test modulation/demodulation
Power Amplifier simulation and test
Completed Altium PCB
All PCBs soldered
Final Testing (Filters)
Final Testing (Modulator)
Final Testing (Demodulator)
Final Testing (Power Amp)

⬛ Completed ⬛ Pending ⬛ Not Started ⬛ Behind Schedule

Validation

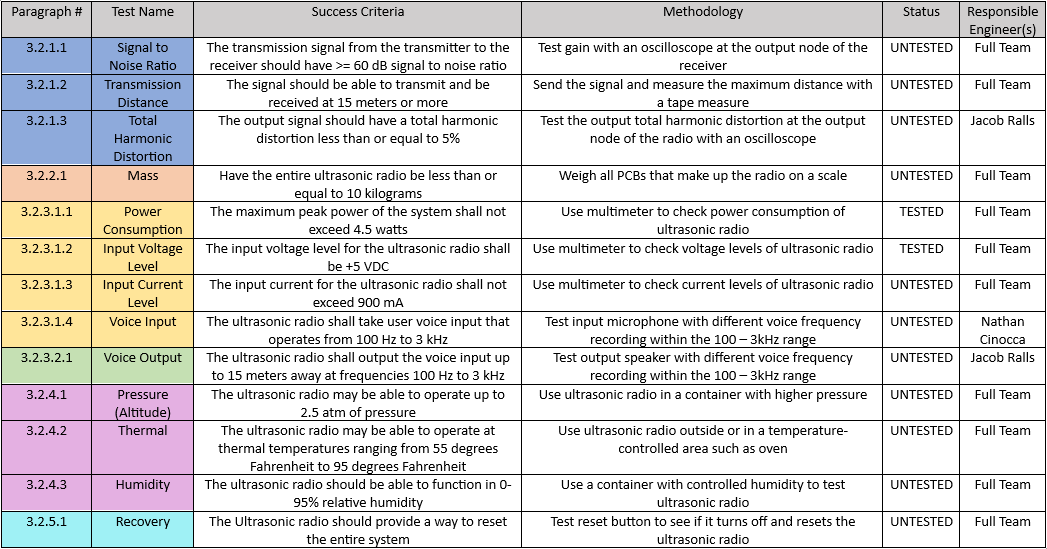
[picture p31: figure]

Schedule and Validation Revision - Draft Ultrasonic Radio
